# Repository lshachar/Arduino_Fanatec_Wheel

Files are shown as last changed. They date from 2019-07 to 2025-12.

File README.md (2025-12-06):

# Arduino_Fanatec_Wheel
A do-it-yourself steering wheel to Fanatec's wheel base.<br/><br/>
**28.04.2020 Coronavirus update:** Version 1 is out!<br/>
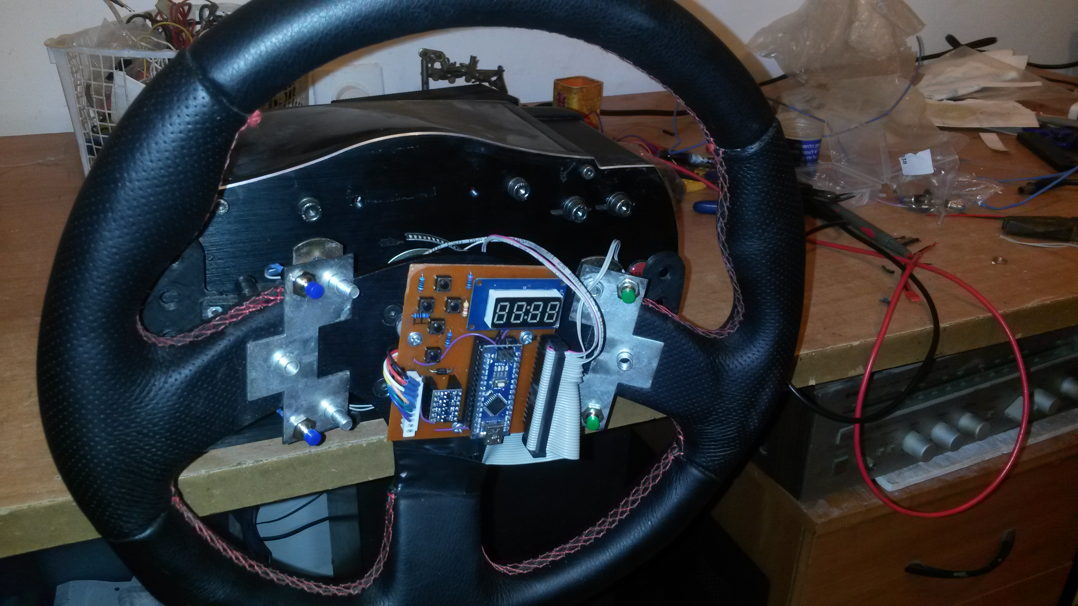
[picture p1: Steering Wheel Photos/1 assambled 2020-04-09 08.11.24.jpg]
Steering wheel assembled

[check out more photos here](https://github.com/lshachar/Arduino_Fanatec_Wheel/tree/master/Steering%20Wheel%20Photos)

*The buttons delay bug is fixed, buttons code is working great!<br/>
*I fixed several large bugs with the SPI communication, which now works flawlessly.<br/>
*Updated schematics - Added a 5 buttons Analog input that feeds into a single analog input on the arduino. You can calibrate your wheel center by using the D-pad and alphanumeric display, without plugging the Arduino to your PC!<br/>
*Added Diode, and connected D2 and D10 together, both changes are necessary! please revise your board to include these changes if you've built one already!<br/>
*Updated board layout - it's possible to either manufacture a single layer board, and solder a few jumper wires for the top layer, or manufacture the complete two-layers board. (I used a CNC machine and milled a single layer board)
________________

**This project is donationware, if my work helped you out** [**maybe get me a beer! :)**](https://paypal.me/lshachar)<br/><br/>
  
Fanatec's wheelbases won't enable any force feedback, unless you have a Fanatec steering wheel attached to it.
With this project, you can use an arduino to communicate with the wheelbase over SPI, which will get the wheelbase working.
You can attach buttons, a D-Pad and an alphanumeric display, for the complete package!

This simplified (schematics) version is enough to let you enable force feedback on your wheelbase,
[use this easy to understand 'breadboard view' simplified schematics](https://github.com/lshachar/Arduino_Fanatec_Wheel/blob/master/schamtics%20arduino%20nano-level%20shifter-fanatec%20round%20plug.png), or [This simplified schematic](https://github.com/lshachar/Arduino_Fanatec_Wheel/blob/master/schamtics%20arduino%20nano-level%20shifter-Simlified.png).

The full PCB supports alphanumeric display, D-pad, and lots of external buttons
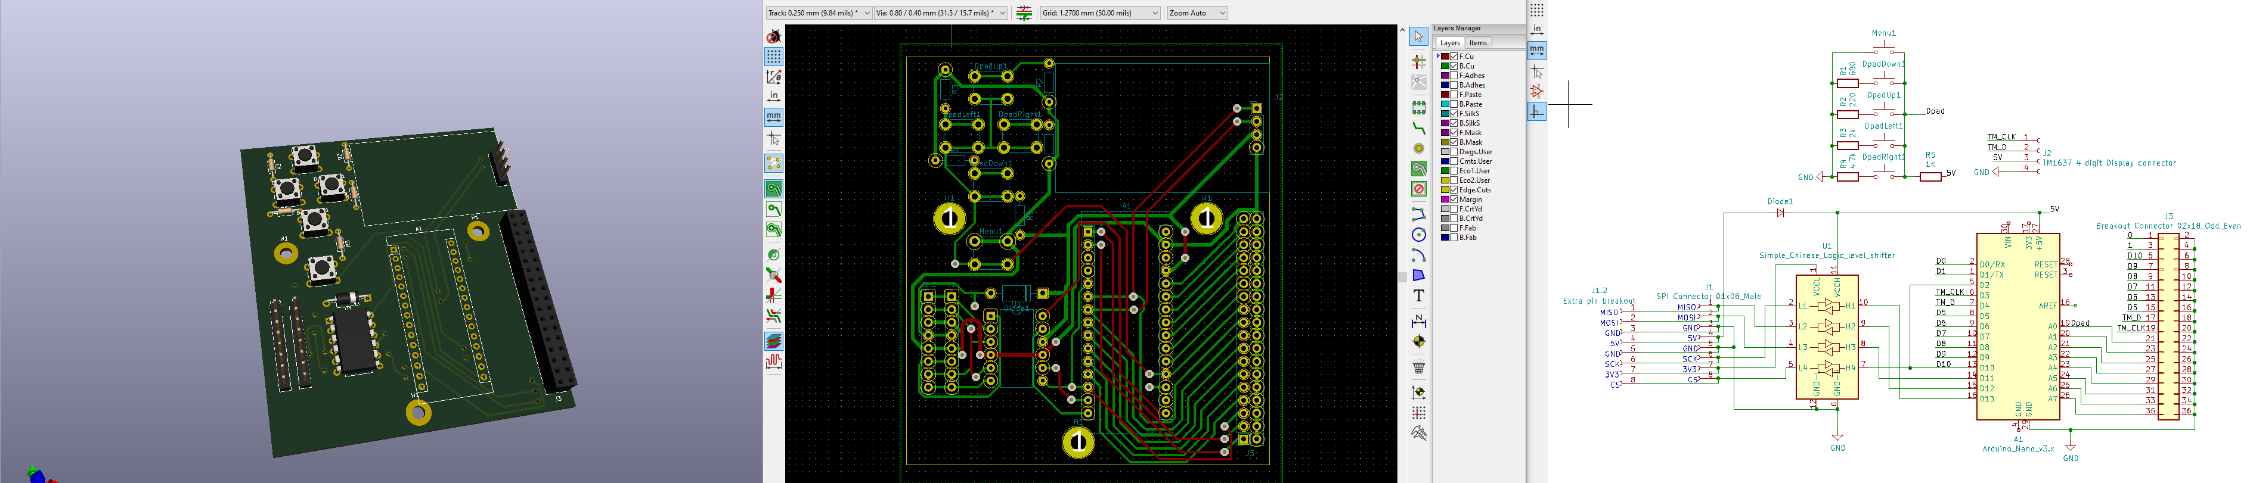
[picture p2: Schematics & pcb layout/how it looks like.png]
full PCB
 (I currently use 6: 2 paddle shifters and 4 buttons on the rim).

Here's a [how to make a male Fanatec SPI connector](Steering%20wheel%20connector%20-%20howto/Readme.md) (what the steering wheel has)<br/>
Also, [Alevale found where to buy the connector](https://github.com/darknao/btClubSportWheel/issues/14#issuecomment-604973137)<br/><br/>
[use this](3d%20Models/fanatec%20adapter%20v1.STL) If you need a simple 3d adapter to attach your physical steering wheel to the wheelbase<br/><br/>

### Several options:
- Use a 5V arduino with a logic level shifter. (recommended, this is what I use. [(here are The schematics)](https://github.com/lshachar/Arduino_Fanatec_Wheel/blob/master/schamtics%20arduino%20nano-level%20shifter-fanatec%20round%20plug.png)
- Use a 5V arduino **without** a logic shifter (can be risky to your precious wheelbase)
- Use a 3.3V arduino (I haven't tried it. They run on 8 MHZ instead of 16 MHZ for the 5V arduinos, but I'm pretty sure 8MHZ should be fast enough.)

Code was tested on arduino Uno and Nano, and works fine. However, they both output 5V and the SPI communication on the wheelbase
is using 3.3V.
It's best to use a level shifter between the two, so there are no chances of damaging the wheelbase (by connecting the 5V arduino 
output to a 3.3V wheelbase input)
However, since the wheelbase is the master and the steering wheel is the slave - MISO is the only *input* channel on the wheelbase,
and it is safe to simply use a voltage divider on the MISO line - to go from 5V level to 3.3V. (The arduino should recognize the 3.3V input signals coming from the wheelbase as high, so there's nothing we have to do there). <br/>
- **Note:** If you do end up going this route, make sure you wire everything up properly, and that you never set SPI as master on the arduino, or you will subject the wheelbase SPI to 5V. (I did subject the wheelbase SPI to 5V by mistake - and nothing got damaged.)<br/><br/>

I recommend using an arduino nano **and** a logic shifter, as seen in the schematics.
- **Note:** The diode is crucial to keep the 5V coming from the wheelbase, and the 5V coming from the computer USB, seperate. the diode will drop the 5V voltage from the wheelbase to ~4.3V, which is fine for the arduino to run on. When you plug the USB cable, the arduino will run on the 5V coming from the computer, and current cannot flow to the wheelbase because of the diode.<br/>
fyi I have connected both power supplies together, and did not have anything go up in smoke. (but this is before I thought about using a diode. DO NOT ATTEMPT THIS YOURSELF.<br/>

[There's a lot of (old) info here](https://github.com/darknao/btClubSportWheel/issues/12)

# What to do if you gotta calibrate your wheelbase center?
On some wheelbases, you can do that directly from the [Fanatec wheel properties page](https://github.com/lshachar/Arduino_Fanatec_Wheel/issues/7). unfortunately it doesn't work on my CSW V2.5.<br/>
You can use the current code to calibrate the wheelbase's center point. (This is needed after a firmware upgrade for the wheelbase) the arduino will translate the alphanumeric display to letters and send them out to the Serial monitor(!). you will need to type in some commands on the Serial monitor, which will look pretty cypheric to you.
Type these characters on the serial monitor, press [return] after each line: <br/><br/>
C		(to change bits on the 3rd byte that affects buttons. C=3rd)
6		(to change (raise) the sixth bit on the 3rd byte, which is the menu button. this will cause the alphanumeric display to turn on and the message '5_1' (equivilent to 'S_1' i.e. 'setting 1') will be printed on the serial monitor.)  
6		(to release the menu button (lower the 6th bit) )  
23		(2 will raise the D-pad button bit, 3 will raise the joystick button bit.)  
23		(to release both buttons, drop both bits)
6		(press the menu button again to exit the menu)  
6		(release the menu button)  
[Watch this If you don't know what I'm talking about](https://www.youtube.com/watch?v=yvhAKxjit8o)  
(Hey - it's not an easy procedure, but it works!)
if you made a PCB with a Dpad and alphanumeric display - you can calibrate the center point without connecting to the computer!
Using the Dpad:
Enter the menu by pressing both up+down bubttons on the Dpad,
S_1 will appear on the serial monitor and on the alphanumeric display,
Press both left+right buttons on the Dpad to calibrate wheel center,
Press both up+down on the Dpad to exit menu. Done!

This project would never have been possible without the work of Darknao on his [BtClubSportWheel - converting any Fanatec CSW steering wheel to a standalone USB version](https://github.com/darknao/btClubSportWheel) project.

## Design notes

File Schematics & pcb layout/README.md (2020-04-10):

I'm keeping the legacy PCB layouts here, as someone may want to use the version 'without display or Dpad' for simplicity.<br/>
please look inside KiCad for the most recent version.<br/>
check out Steering Wheel Photos folder, for photos describing how I have everything connected.<br/><br/>

I did not manufacture this PCB properly in a factory, but rather I milled it on a CNC machine. I used a single layer PCB (for the buttom layer in green), and the top side (red)
was meant to be connected with some jumper wires.<br/>
So, I was using vias on the design as plated through-holes, as means to attach wires to. (AFAIK there will not be holes if you sent the gerber files to a factory. The PCB layout file must be edited to create a hole first!)<br/>
note that I didn't even bother placing some of the lines (appear as white lines in the layout file) since jumper wires can easily cross over each other. with a bit of editing, all these things can be fixed so that you could get a good working PCB right from the factory.<br/>
I see that not all TM1637 display boards have the same connector, you might need to switch the order of some of the pins, or move them from the top right corner of the PCB, towards the D pad buttons, on the top left of the PCB.<br/>
The diode solves the issue I had with connectiong the wheelbase's 5V supply with the USB 5v supply coming from the computer, so it's really important.<br/>
you can use almost all the pins on the large breakout connector (J3) for buttons, except the last two - D0 and D1 on arduino are also the serial communication pins. so they are there just for debugging.<br/>
It would be useful to add another row of 8 pins to the left of J1, in order to have breakout pins for the SPI communications with the wheelbase. <br/>
AREF - there is a via, but it's not used. (it was connected to the + side of the diode, (there is a via there as well)) but it's not used. In fact, using it would create problems with the dpad buttons that are on the layout.<br/><br/>

Good luck!

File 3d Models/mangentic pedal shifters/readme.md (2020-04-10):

Non Commercial -  NOT FOR RESALE - Personal use only. 

Copyright AMSTUDIO 2018 All Rights Reserved

AMSTUDIO
https://www.youtube.com/channel/UCQS1ZB3BVSrBo3tCs7PyfxQ

Magnetic shifters video:
https://www.youtube.com/watch?v=hbHkliQDCx0

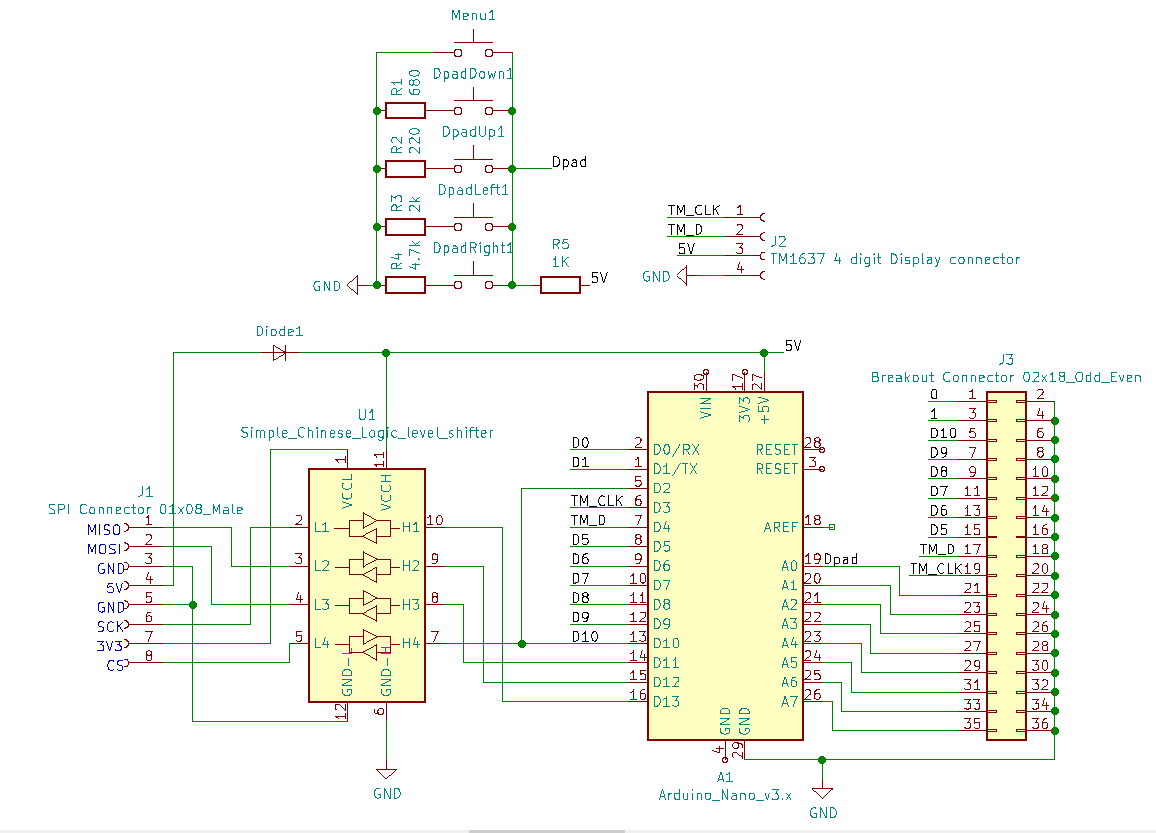
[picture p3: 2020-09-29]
schamtics arduino nano-level shifter-Full.png

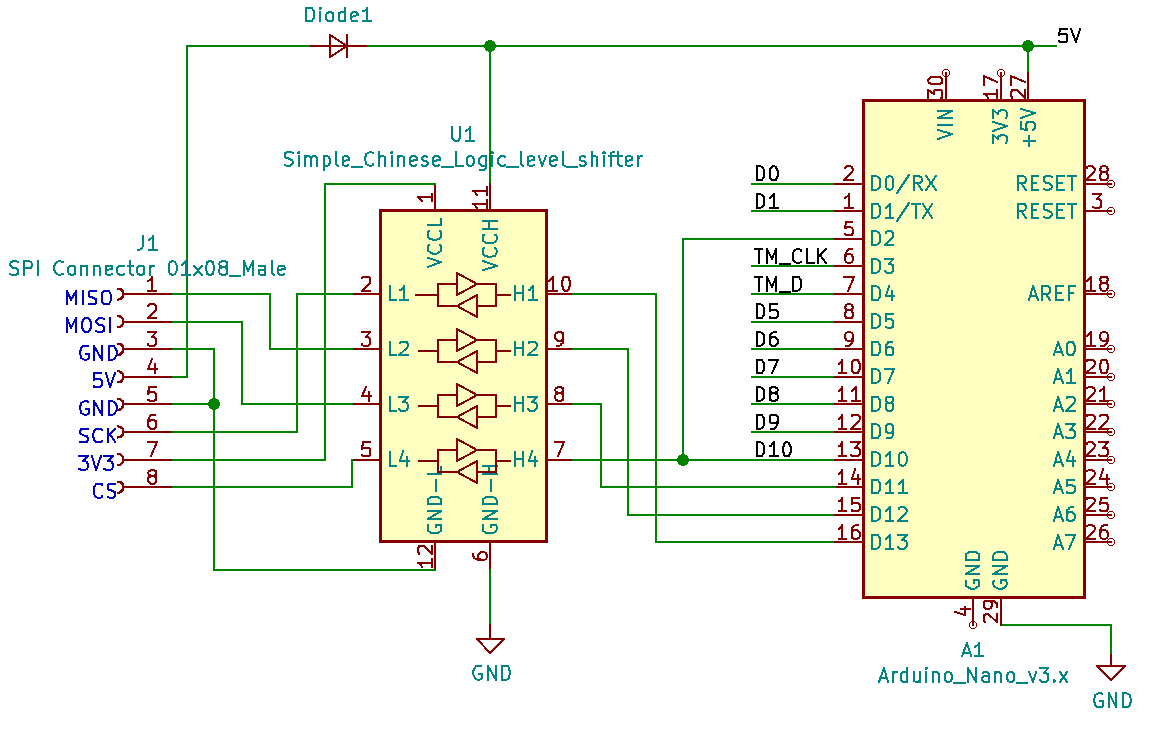
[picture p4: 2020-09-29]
schamtics arduino nano-level shifter-Simlified.png

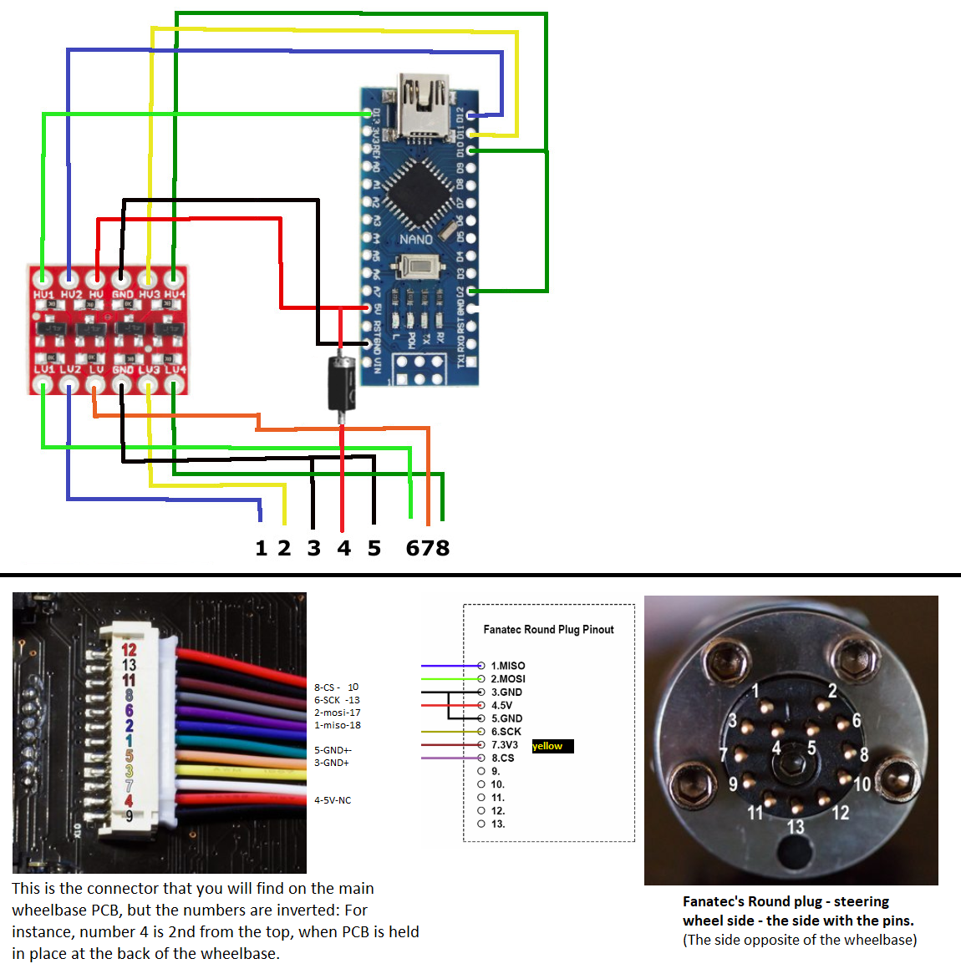
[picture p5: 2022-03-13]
schamtics arduino nano-level shifter-fanatec round plug.png

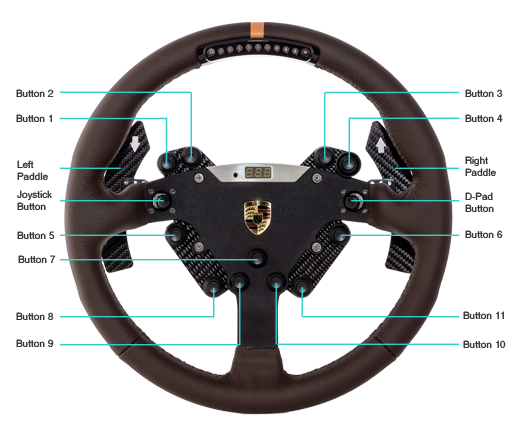
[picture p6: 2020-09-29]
clubsport Porsche 911 buttons.png

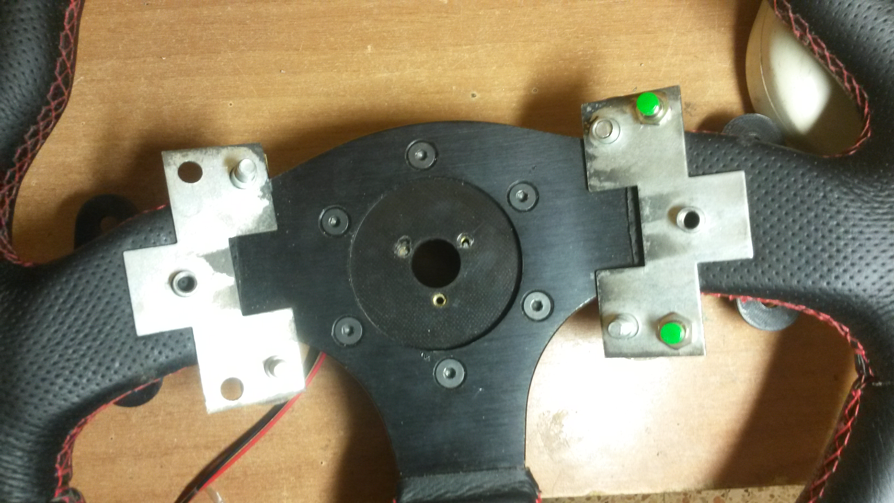
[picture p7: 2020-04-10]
Steering Wheel Photos/2020-03-29 04.42.22.jpg

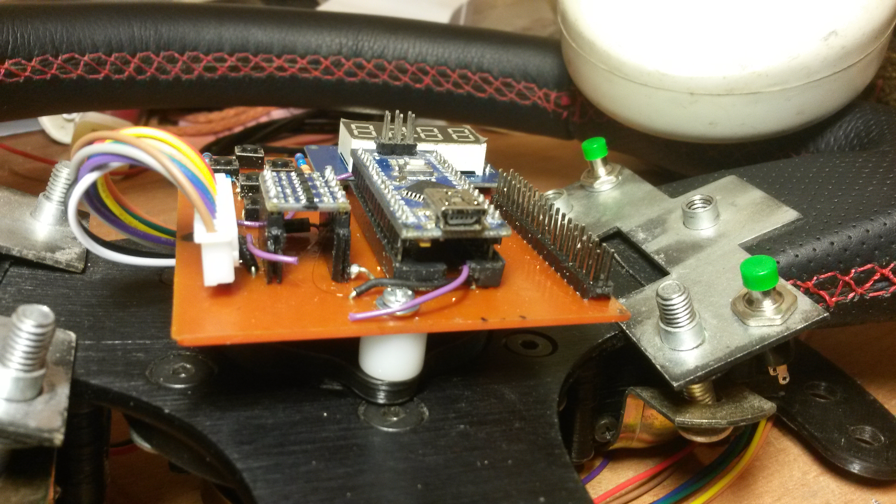
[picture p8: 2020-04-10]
Steering Wheel Photos/2020-03-29 04.53.28.jpg

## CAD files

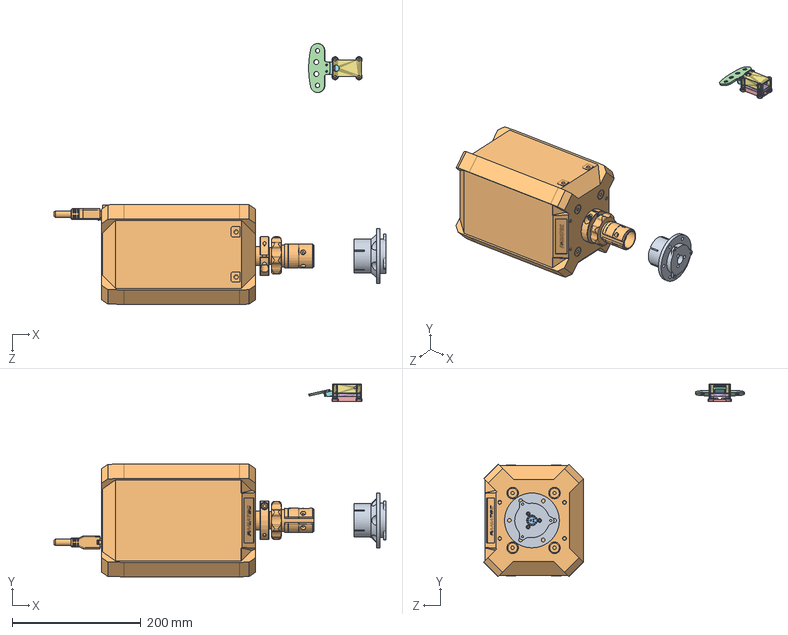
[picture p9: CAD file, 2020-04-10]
3d Models/fanatec adapter & pcb fixtures/arduino fanatec wheel.SLDASM
515.1 x 298.9 x 404.6 mm
fanatec adapter
Fanatec_PodiumWB-DD1-DD2
fanatec SPI connector
f1_paddle
shifter_unit_btm
shifter_unit_switch_stop_plate
shifter_unit_top
paddle_hinge_v2

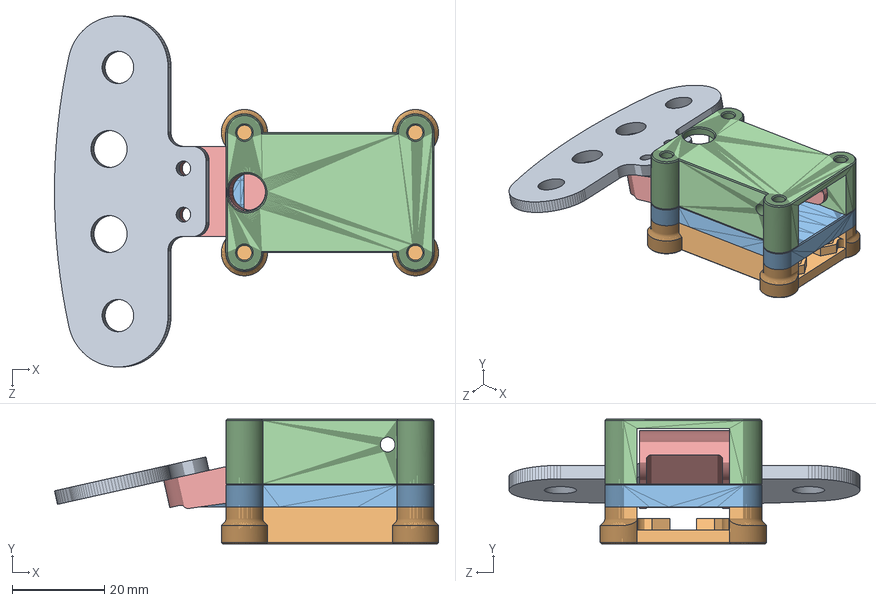
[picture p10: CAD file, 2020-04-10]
3d Models/mangentic pedal shifters/Imported to Solidworks/mangentic pedal shifters assy.SLDASM
83.1 x 27.0 x 75.9 mm
f1_paddle
shifter_unit_btm
shifter_unit_switch_stop_plate
shifter_unit_top
paddle_hinge_v2

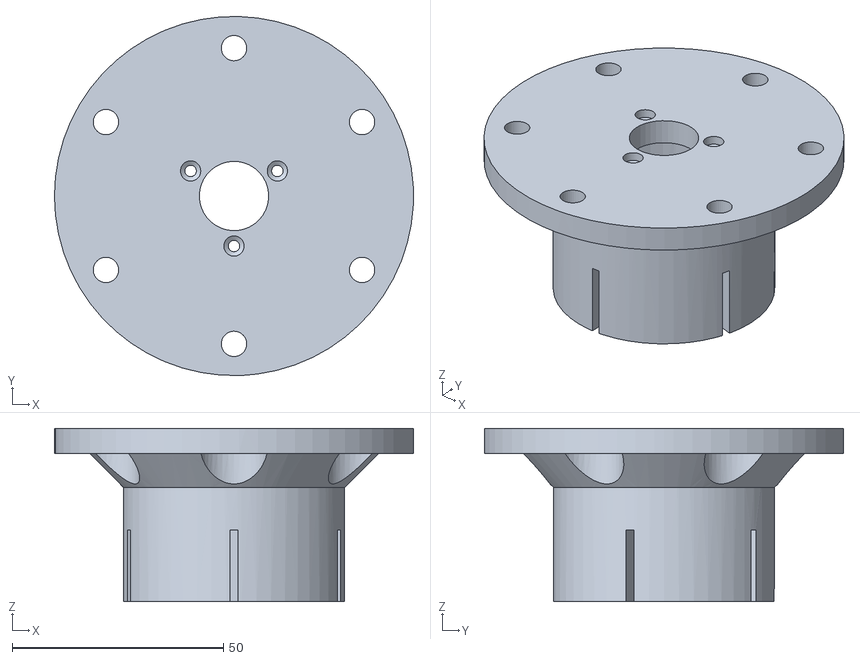
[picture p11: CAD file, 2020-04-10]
3d Models/fanatec adapter & pcb fixtures/fanatec adapter & pcb fixtures exported files/fanatec adapter V2.STL
85.0 x 85.0 x 41.0

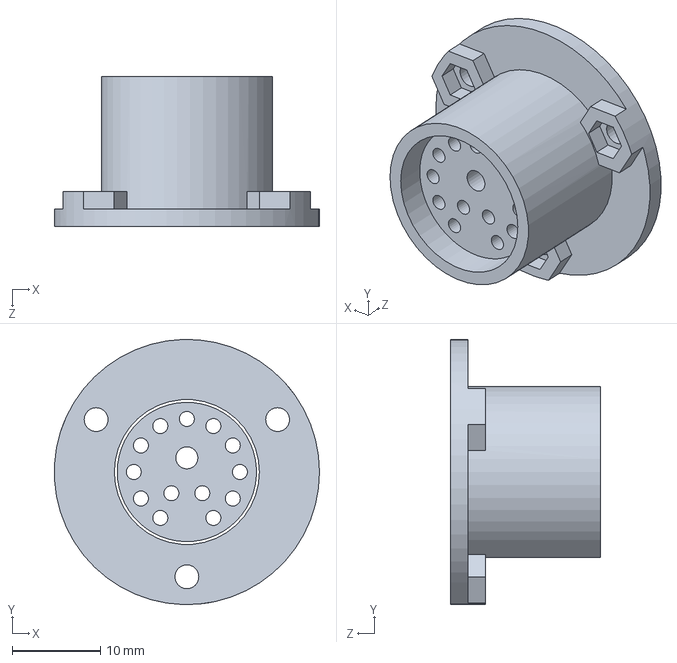
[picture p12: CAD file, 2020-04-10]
3d Models/Fanatec SPI connector/fanatec SPI connector.SLDPRT
30.0 x 30.0 x 17.0 mm

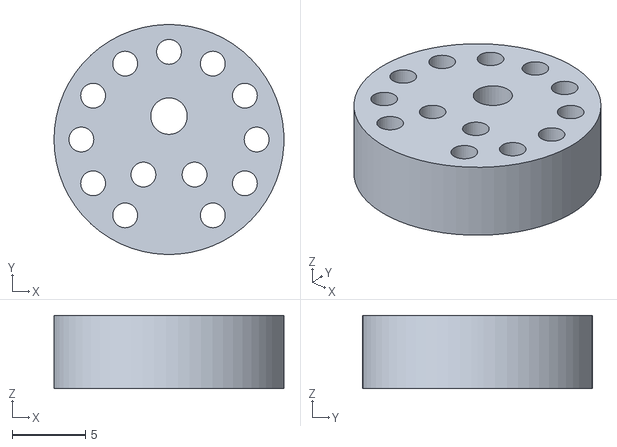
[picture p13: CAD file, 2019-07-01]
3d Models/Fanatec SPI connector/SPI connector exported files/fanatec SPI connector.STL
15.8 x 15.7 x 5.00

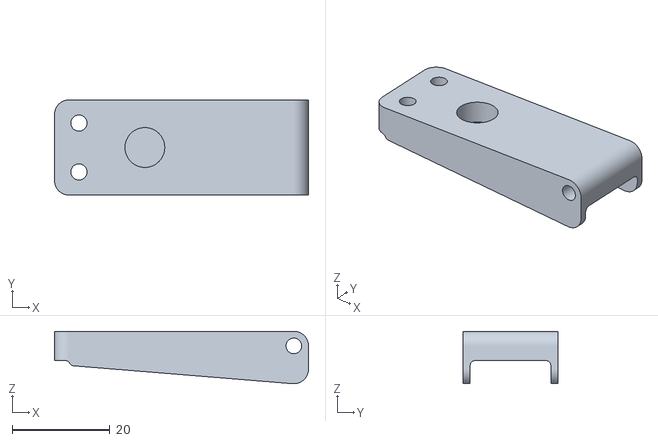
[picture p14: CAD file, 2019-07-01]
3d Models/mangentic pedal shifters/Imported to Solidworks/10mm round magnet (instead of 8) exported files/paddle_hinge_v2.STL
52.0 x 19.5 x 10.7

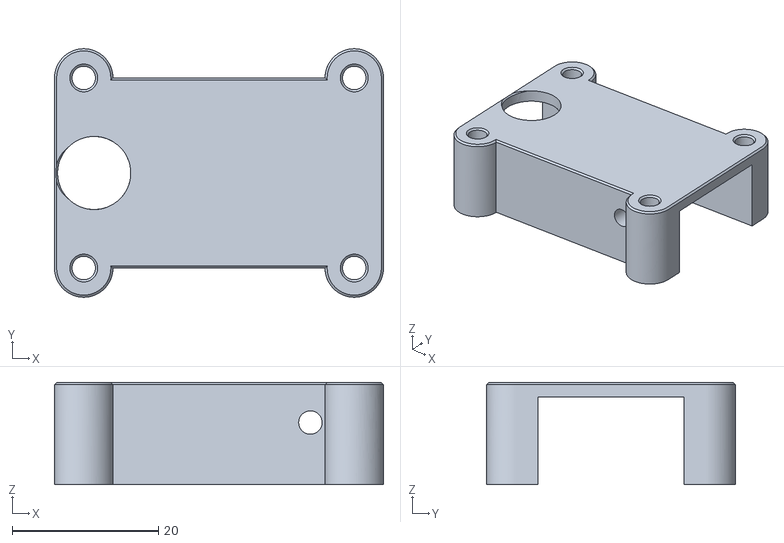
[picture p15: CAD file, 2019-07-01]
3d Models/mangentic pedal shifters/shifter_unit_top-10mm x 5mm magnet (Shachar).STL
45.0 x 34.0 x 14.0

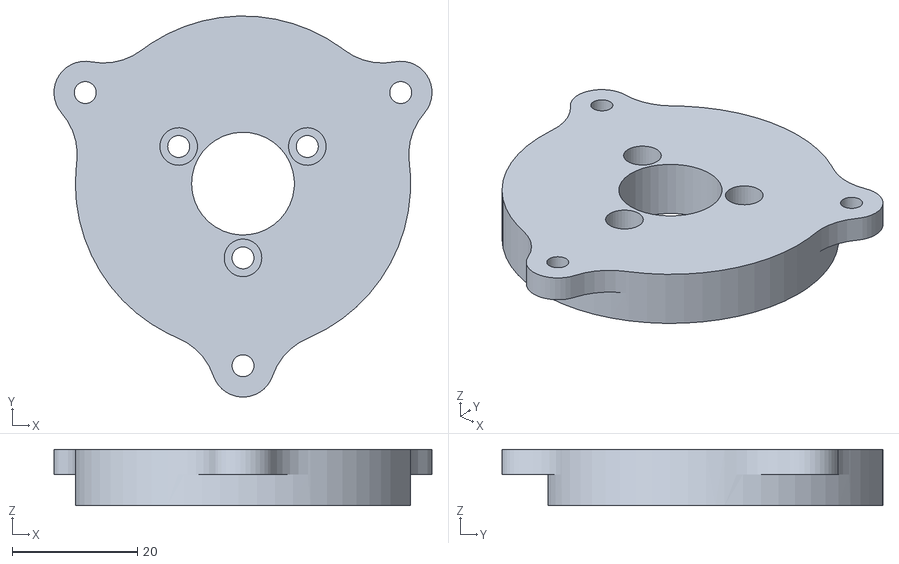
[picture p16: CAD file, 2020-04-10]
3d Models/fanatec adapter & pcb fixtures/fanatec adapter & pcb fixtures exported files/pcb fixture.STL
60.3 x 60.8 x 9.00

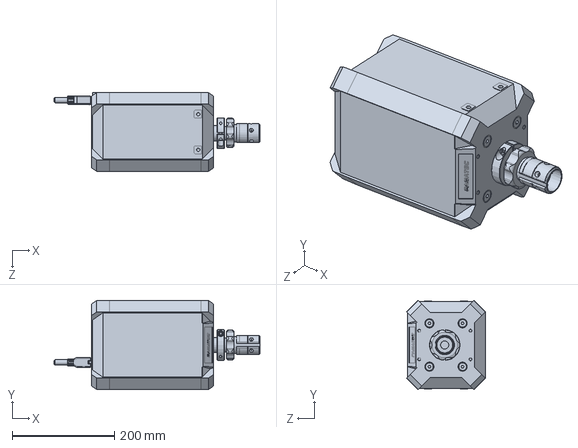
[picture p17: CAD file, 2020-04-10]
3d Models/fanatec adapter & pcb fixtures/Fanatec_PodiumWB-DD1-DD2.SLDPRT
403.6 x 175.0 x 155.0 mm

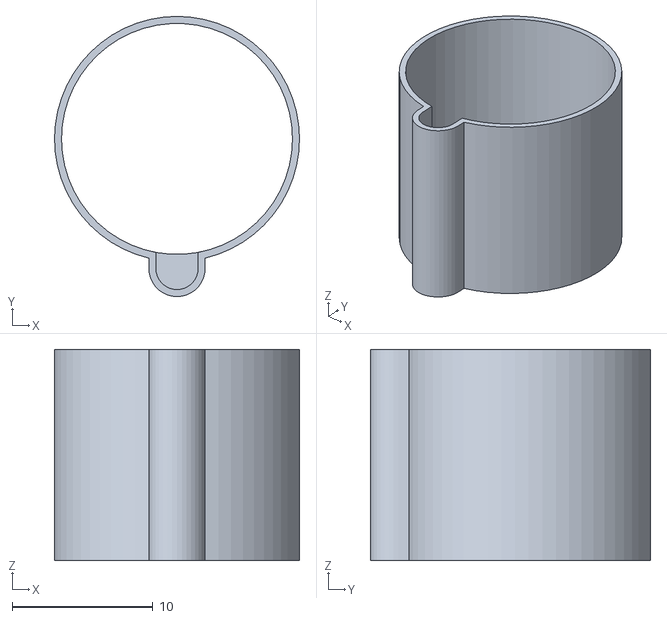
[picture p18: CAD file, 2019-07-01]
3d Models/Fanatec SPI connector/SPI connector exported files/fanatec SPI connector-housing.STL
17.4 x 19.9 x 15.0

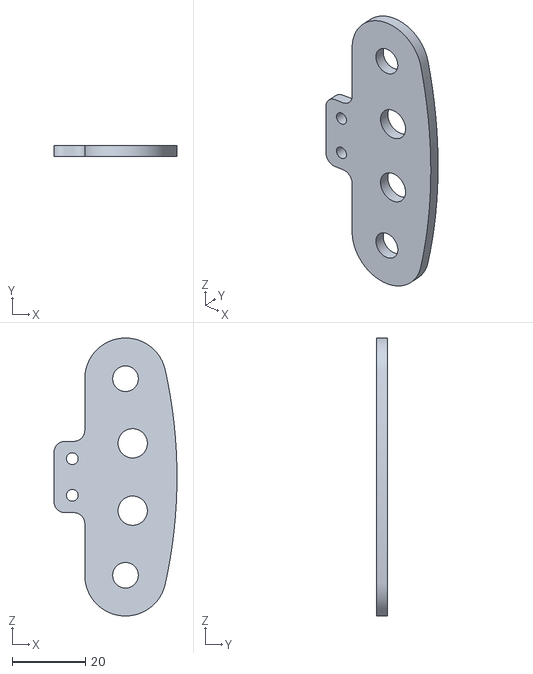
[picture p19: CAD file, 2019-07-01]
3d Models/mangentic pedal shifters/Imported to Solidworks/10mm round magnet (instead of 8) exported files/f1_paddle.STL
33.6 x 3.00 x 75.9

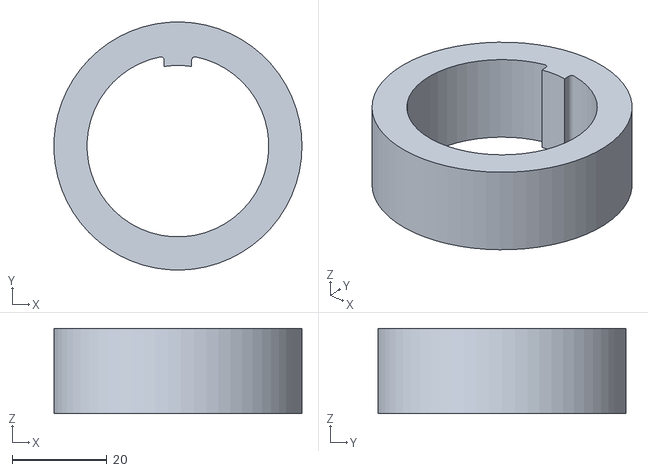
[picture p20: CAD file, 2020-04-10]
3d Models/fanatec adapter & pcb fixtures/fanatec adapter & pcb fixtures exported files/fanatec adapter V2 - a test part to calibrate print on base.STL
52.3 x 52.3 x 18.0

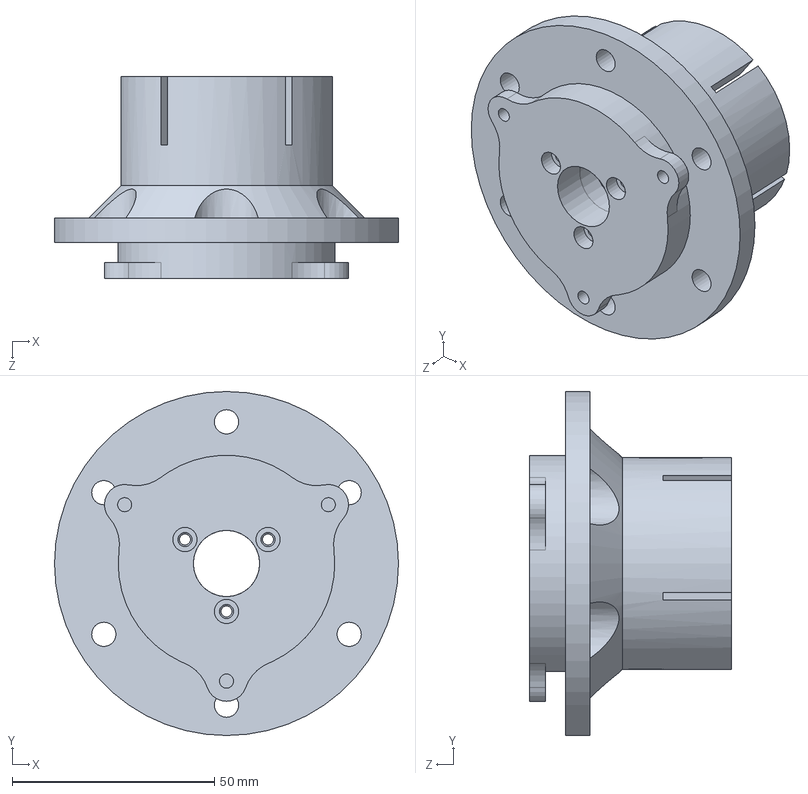
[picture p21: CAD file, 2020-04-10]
3d Models/fanatec adapter & pcb fixtures/fanatec adapter.SLDPRT
85.0 x 85.0 x 50.0 mm

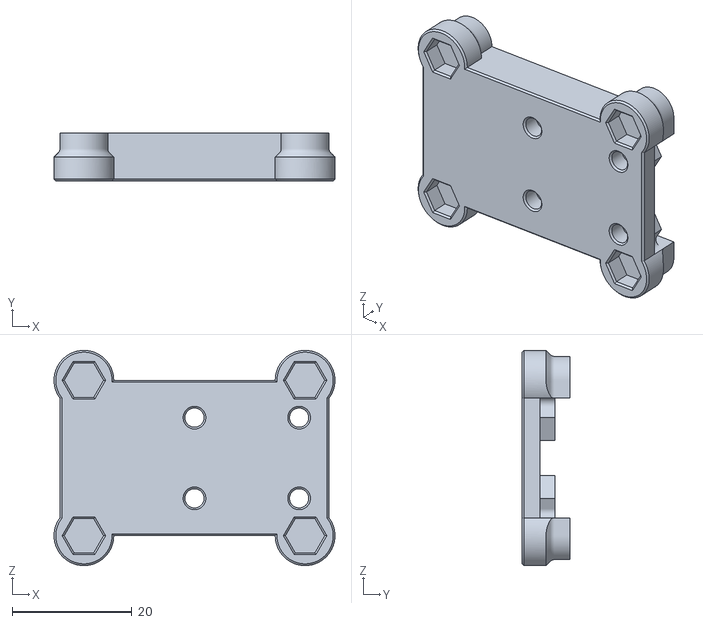
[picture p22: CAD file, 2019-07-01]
3d Models/mangentic pedal shifters/Imported to Solidworks/10mm round magnet (instead of 8) exported files/shifter_unit_btm.STL
47.0 x 8.00 x 36.0

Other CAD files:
3d Models/mangentic pedal shifters/Imported to Solidworks/paddle_hinge_v2.SLDPRT
3d Models/mangentic pedal shifters/paddle_hinge_v2-10mm x 5mm magnet (Shachar).STL
3d Models/mangentic pedal shifters/Imported to Solidworks/10mm round magnet (instead of 8) exported files/shifter_unit_top.STL
3d Models/mangentic pedal shifters/Imported to Solidworks/f1_paddle.SLDPRT
3d Models/fanatec adapter & pcb fixtures/fanatec adapter & pcb fixtures exported files/fanatec adapter V2.x_t
3d Models/fanatec adapter & pcb fixtures/fanatec adapter & pcb fixtures exported files/fanatec adapter v1.STL
3d Models/fanatec adapter & pcb fixtures/fanatec adapter & pcb fixtures exported files/pcb fixture.x_t
3d Models/mangentic pedal shifters/Imported to Solidworks/10mm round magnet (instead of 8) exported files/shifter_unit_switch_stop_plate.STL
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

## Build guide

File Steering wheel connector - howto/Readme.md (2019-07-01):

Extract the female plastic SPI connector from your wheelbase
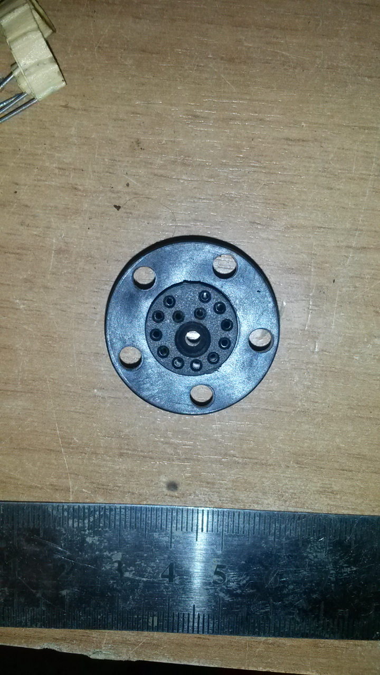
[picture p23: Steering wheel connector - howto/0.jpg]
Fanatec female SPI connector


And the wired connector that connects to the wheelbase PCB
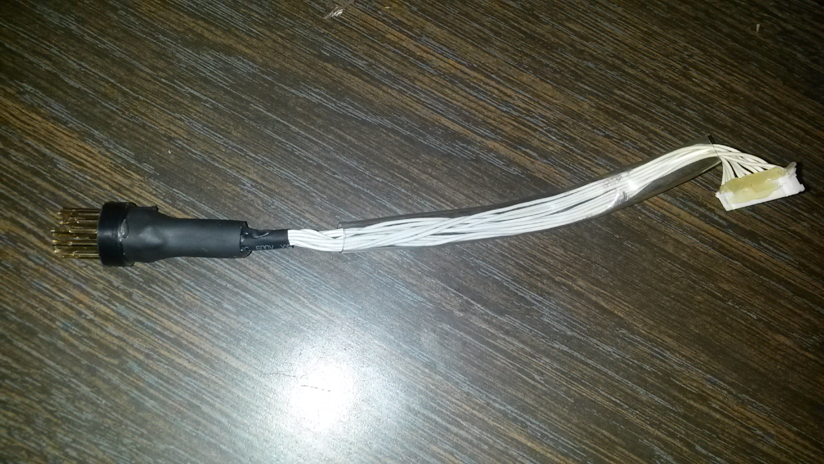
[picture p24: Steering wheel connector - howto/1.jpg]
wired connector

Use the small ellen screw (that you had to remove) to assemble the two pieces back together.

solder some pins on pieces of wires (I recommend you to get something golden. I was lazy! It might rust out eventually!)
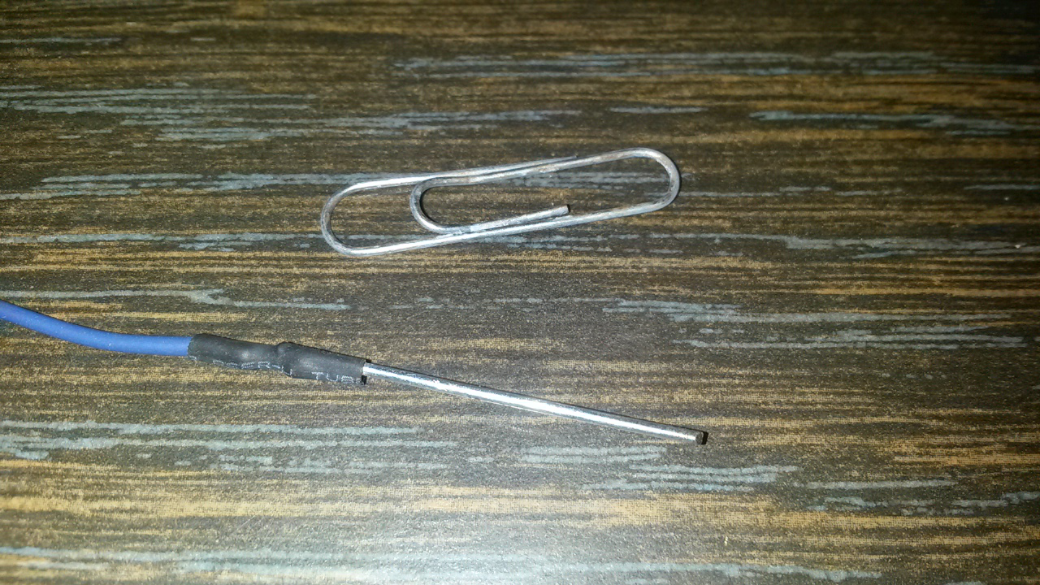
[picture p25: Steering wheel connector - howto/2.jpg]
wire with pin

The connector has 13 connections, but you probably won't need all of them. However adding more will be impossible later. So I just did all of them.

[3d print this part](3d%20Models/Fanatec%20SPI%20connector/fanatec%20SPI%20connector-housing.STL)

put a small piece of adhesive tape to cover all the holes of the female plastic part. (don't use anything fancy, if it's really sticky mess it up a ittle bit with some finger oil - touch the sticky side.)
The 3d printed part should fit with the aligning indentation mark as shown in the photo. (indentation pointing down, Allen screw is at the top) See that it fits, and take it off.
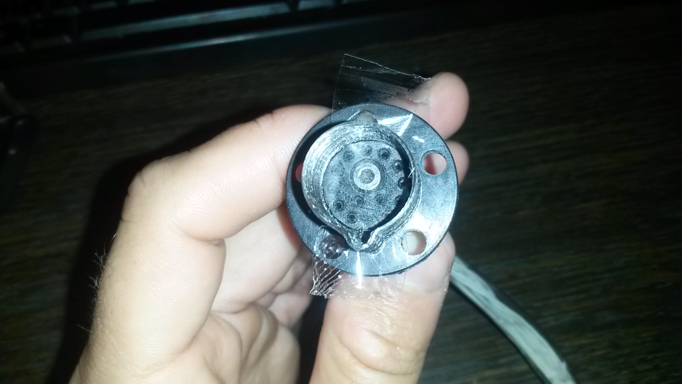
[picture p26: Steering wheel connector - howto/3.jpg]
adhesive tape and 3dprint


force all the pins through the adhesive tape.
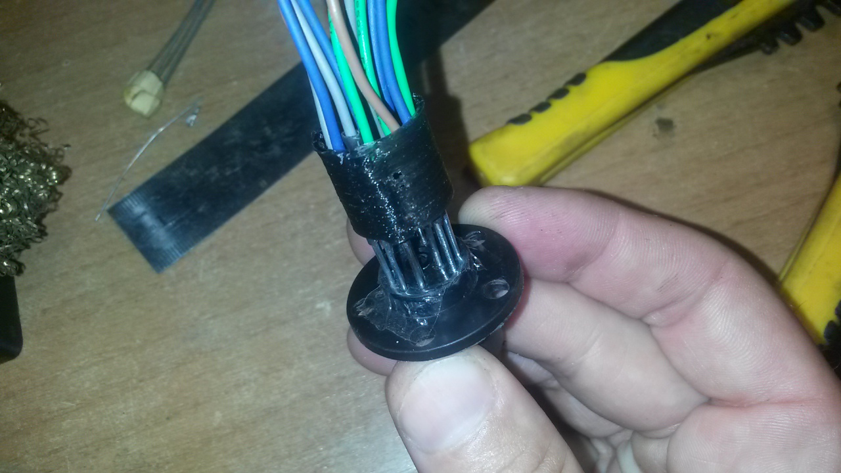
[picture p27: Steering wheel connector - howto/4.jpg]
with wires


put the 3d plastic part back to its place
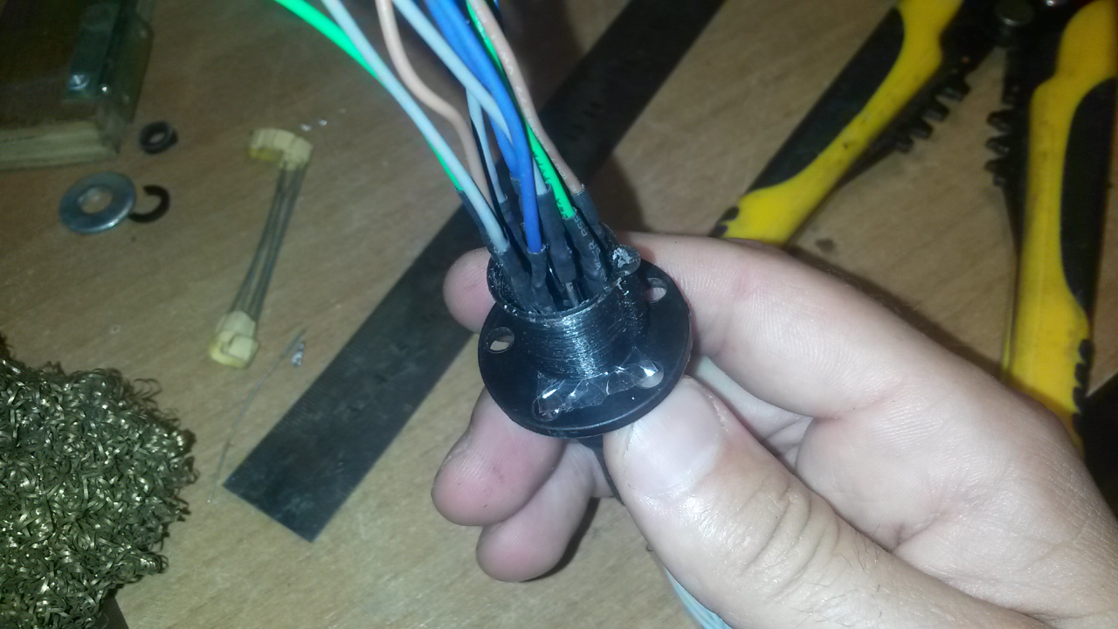
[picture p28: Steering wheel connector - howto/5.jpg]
ready to cast


you are now ready to cast your connector in Epoxy resin.
Use 2 hours cure time epoxy, or you are not likely to fill in all the air gaps by the time the epoxy sets.
I only had 5 minutes epoxy lying around, so I have to do it in another time... to be continued.
(after the epoxy sets, release your new connector, and probably break the 3d printed part where it overlapped with the connector.)

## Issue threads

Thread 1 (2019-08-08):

Buttons

devActive527, 2019-08-08:
Well done. I didn't do the tests, but I see you implemented the buttons. Are they working properly? What do you think there is a chance using arduino uno to additionally handle several buttons and e.g. display data on hd44780 or some other display?

Closed 2019-08-10.

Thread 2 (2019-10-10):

Made the connector with an Nano, Level Shifter, the schematic and code, but no good

Jonbakhol, 2019-10-10:
@lshachar

Hi Ishachar, I used the connection schema (the good one, not mine)
I soldered all wires correctly to the Level Shifter and to the pins. I uploaded the sketch arduino_fanatec_wheel.ino provided on https://github.com/lshachar/Arduino_Fanatec_Wheel/blob/master/arduino_fanatec_wheel.ino

And plugged it in the wheelbase. But no ClubSport Porshe 918 RSR is shown.

Is there something else I have to do? Press the reset button on the Nano or something else?

I also have an Teensy 3.2 with the Teensy code, and that one is working perfectly.

Any help would be appreciated.

Thanks
JonBakhol

lshachar, 2019-10-10:
Hi! no reset is needed. Do you have both pins 3 & 5 connected to ground?
If you have a logic analizer, or a scope see if you get clock signal on fanatec's pin 8. (or simply attach an LED and a resistor to HV4 on the level shifter)

Jonbakhol, 2019-10-10:
Thanks for coming back so quick.

Yes I connected them both to ground. Measured with an ohm meter all pins to be sure no short-circuits are there (accept pin 3 & 5).
Scopes etc I  don't have. I do have some LED's and resistors. Between which point do I need to check it? HV4 and ?

Few more (maybe stupid) questions:
Do I need to connect the modified USB cable to it? (without the 5V cable)
Could it be the cheap Chinese Nano?
Do I need to put in the missing pins 9 till 13 (even there is no connection between the Nano and the pins)

Thanks for now

lshachar, 2019-10-10:
(Alright this got messy because I didn't finish my initial reply but pressed comment by mistake.)

Hi! no reset is needed. Do you have both pins 3 & 5 connected to ground?
try plugging your arduino to the PC by usb. It might get the thing to recognize if your grounds / +5v lines aren't connected well.
If you have a logic analizer, or a scope, test your logic shifter. you are suppose to get information coming in from the base on CS, MOSI, CLK lines. the arduino should send out data on MISO line.

Last thing... could be interference... Darknao said he had issues with interference so I had a ground wire twisted around each data line. I don't think it's likely to solve your problem and I hardly think it was necessary to twist some ground lines.

_____________________
answering your 2nd comment
> Do I need to connect the modified USB cable to it? (without the 5V cable)

well, The simple answer is - preferrably yes.
or at least, disconnect fanatec's pin #4  (5v supply) from the arduino, before you connect the arduino to the PC by USB.
This way, you're making sure that the arduino gets voltage from the computer and you don't connect the two power supplies to each other.
However, I definitely forgot to do that myself several times and nothing went up in smoke.
In any case you really want to get the arduino connected to the PC because you need to open the serial monitor on the PC and tell me what you see there!

> Could it be the cheap Chinese Nano?

Yes, that's what I use.

> Do I need to put in the missing pins 9 till 13 (even there is no connection between the Nano and the pins)

nope. you don't need to do anything with them.

> Thanks for coming back so quick.

lucky you.. I was on the computer :)

> Scopes etc I don't have. I do have some LED's and resistors. Between which point do I need to check it? HV4 and ?

... and ground. This is kind of long to explain, I basically offered you to check that the logic shifter was working properly, with a single LED, which isn't the best test. so I take it back, it will be difficult for you to understand if there is data transmission on the line with a single LED. instead you can test that the logic shifter is working properly. By raising one side of the logic shifter (LV# or HV#) to high - the other side should also go high. but each side will only output the voltage that it gets on its power supply pin (marked by LV or HV on the schematics, next to the GND pin)
so, if you give +5v and ground to the HV side, and you give +3v and ground to the LV side, and then you give, for instance, +3v to LV1, then HV1 should go up to +5v. you can test it with a multimeter. if you have the project right now on a breadboard, this should be a really simple test to do..
So, you are trying to debug electronically. but try the serial monitor first.

Jonbakhol, 2019-10-11:
Goodmorning @lshachar ,

I connected the Arduino to the PC with an intact USB cable (so no 5V cable cut) and checked with the multimeter the currents on the Level Shifter, on LV side and on HV side.
These are the values:

              LV side                                                                                HV side

GND + LV1 (pin 6) = 2,28 V                                                     GND + HV1 = 2,11 V
GND = LV2 (pin 1) = 3,26 V                                                     GND = HV2 = 4,66 V
GND = LV   (pin 7) = 3,26 V                                                     GND = HV   = 4,66 V
GND = LV3 (pin 2) = 3,26 V                                                     GND = HV3 = 4,66 V
GND = LV4 (pin 8) = 3,26 V                                                     GND = HV4 = 4,66 V

Except pin 6 (LV1 and HV1) all seems fine, or isn't it?
What could be the problem that pin 6 (LV1 and HV1) is that low?

Can I try to change pin6 (which is connected to D13) to e.q. D10 and update the sketch?

Many thanks again.

Jonbakhol

devActive527, 2019-10-24:
@lshachar ,

Hi. I don't know if it will help in some way, but I noticed that when I connect the 5v power supply to the arduino shortly after turning on the base there are no crc errors, while when I do it too early or too late there are errors. I discovered this while reading the com port from arduino. Maybe this is the reason for the buttons not working? Simply 5v power supply to the steering wheel should appear with some delay, and in our connection is given immediately after switching on. I do not know how it relates to the communication between the base and the steering wheel is just my theory. Can you verify it somehow?

lshachar, 2019-11-16:
CRC errors means you have bad wiring / bad ground / noise issue. Since the button delay problem happens even when there are no CRC errors - the two aren't related.

lshachar, 2020-04-28:
[The new diagram](https://github.com/lshachar/Arduino_Fanatec_Wheel/blob/master/schamtics%20arduino%20nano-level%20shifter-fanatec%20round%20plug.png) and fixes I made to the SPI communication, means everything works much better now.

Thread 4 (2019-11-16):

DIY arduino steering wheel to fanatec csl elite wheelbase

Pistolidas, 2019-11-16:
Hello All,

Has enyone been able to get either the Teensy 3.2 or the Arduino Nano working on a Fanatec CLS Elite V1?
I tried both, but no succes. :(

Regards,

Pistolidas

MagnusThome, 2019-12-16:
I have it working on a CSL Elite+ base

https://rejsa.nu/forum/viewtopic.php?p=1588680#1588680

Pistolidas, 2019-12-16:
Hello Magnus,

Thnaks for your message. Would you be willing to share your connections and arduino sketch?
Are you using a teensy 3.2?

Looking forward to your reply.

Regards,

Pistolidas

MagnusThome, 2019-12-17:
Hi!

I use an Arduino Nano with his code just as is with no changes:

https://github.com/lshachar/Arduino_Fanatec_Wheel/blob/master/arduino_fanatec_wheel.ino

I also connected everything 100% according to his diagram:

https://github.com/lshachar/Arduino_Fanatec_Wheel/blob/master/schamtics%20arduino%20nano-level%20shifter-fanatec%20round%20plug.png

It works right away. I did almost make a mistake though connecting the wires to the home made connector going into the base unit’s axle connector. I misread the connection diagram mirrored, to be viewed as you solder the pins towards the base unit, but it’s viewed in the picture from the base outwards. Just double, triple, quadruple check all the wiring is my tip.

Email me again if you have any more questions!

/Magnus

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

Pistolidas, 2019-12-18:
Hello Magnus,

Thanks for very much for your reply.
I also made this unit and it works on a Clusport V1 wheelbase but not on my Elite V1 wheelbase. Would you know which firmware version and which driver version you have installed for your CSL Elite wheel base.

Kind regards,

Pistolidas

MagnusThome, 2019-12-18:
The Fanatec propertiy page in Windows says:

PC driver: 328
WB FW: 630

But I've found a problem, depending on what Aduino board I use it works or not.

With the working board:
- When I plug it in to the base the base unit's red power led fades down and up once and then the Clubsport wheel shows up on the windows property page
- All four data pins have signals, measured with a scope

The not working board:
- When I plug it in to the base the base unit's red power led fades down and up coninously. The Clubsport wheel never shows up on the windows property page
- Three data pins have signals, measured with a scope. They look like on the working board but they are there for a second, gone for second, there for a second, and so on.
- D12 is low all the time. No signal visible at all like on the working board. Tried a 4K7 pull up resistor to 3V3 but no change.

lshachar, 2019-12-26:
> I also made this unit and it works on a Clusport V1 wheelbase but not on my Elite V1 wheelbase.
> Pistolidas

Does your Elite V1 Wheelbase works with a different wheel?
In case you haven't tried - I suppose that the wheelbase is at fault
If you have tried and it works - I'm really surprised! Follow MagnusThome's advice: 'Just double, triple, quadruple check all the wiring is my tip'

MagnusThome, 2019-12-26:
Pistolidas, did you connect the two ground pins to each other? Its a long shot but might affect the function a bit differently on different base version, who knows...

lshachar, 2019-12-27:
> Pistolidas, did you connect the two ground pins to each other? Its a long shot but might affect the function a bit differently on different base version, who knows...
It actually isn't a long shot, without the two grounds connected, my CSW V2.5 will not recognize anything. it must be connected in order to work.

Pistolidas, 2019-12-27:
Hello Magnus and Ishachar, thanks for your help. I ordered a new Arduino Nano and I'll give this a try this weekend.
With the "old" Nano I have connected the GND to both pins 3 and 5 of the round connector to the wheel base, as described here:

https://github.com/lshachar/Arduino_Fanatec_Wheel/blob/master/schamtics%20arduino%20nano-level%20shifter-fanatec%20round%20plug.png

I double checked the connections ones more and all seems to be okay.

I have two wheels for my Elite wheel base the Fanatec XBOX P1 and the Fanatec McLaren GT3 both work properly.

I have also tried the Teensy 3.2 setup as described here: https://github.com/darknao/btClubSportWheel/issues/12

This also only worked on a Clubsport V1 and not on my Elite V1.

I hope the new Nano will work but I have my doubts, to be continued.......

Pistolidas, 2019-12-29:
It worked, I replaced the Aruino Nano and it recognized it as the Clubsport Porsche 918 RSR wheel, Force Feedback works.
Thanks for your help!!

DavDaddy, 2020-12-13:
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

Not to hijack this thread but does anyone have any idea if this will work with the ClubSport v1 wheelbase?

I know the Porsche 918 wheel is compatible so I figure it should but I wanted to double check before I rip my DIY HOTAS apart?

Thanks.

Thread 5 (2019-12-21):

Adapting to Clubsport V2.5

matt0hait, 2019-12-21:
I'm working on adapting this to my Clubsport V2.5 using an ESP32. I'm a little stumped on the pinout. It seems different from the one provided in the repository. I thought that the Fanatec rims were compatible between the bases. I'm limited in my options since I don't have a Fanatec rim yet. This is what I found so far by probing the base's PCB:

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

Anyone else take a crack at this yet?

MagnusThome, 2019-12-22:
I'm a bit confused with your pinout numbering. This is the original connector numbering?

The four uncommented pins are 5V, GND, +D, -D

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

MagnusThome, 2019-12-22:
This pinout works on a CSL Elite + I have here and it defintely works with the same steering wheels as with your Clubsport V2.5

matt0hait, 2019-12-22:
Just re-probed with my oscilloscope, (using the pin map you provided) I have 5V on pin 11 &13. Pin 4 definitely connects to ground for me. I was able to continuity check it to a Vss pin. Is it possible that the rims provide 5V to the base through pin 4?

I'll have some level converters later this week. Saw some diagnostic pins on the inside of the base. Gonna see if they can spill the beans.

matt0hait, 2019-12-26:
(Using your pin map again) Pin 3 does output 3.3V, but once it is pulled to ground the signals become alive. I'm still not receiving any signals on MISO or MOSI. Using the serial interface on the arduino doesn't create any signals either. Think I'm going to need to try another arduino.
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

lshachar, 2019-12-26:
When I initially tried to implement this I wanted to go the ESP32 route, but as far as I can remember - nobody was able to put it in ISP Slave mode. Even though some documentations were referring that.
I advise you to try getting your ESP to receive data as an ISP slave, before attempting to use the code.
(Actually, I would advise you to get it working on an arduino first... would probably make your life much easier)

danieleibarra, 2019-12-28:
Has anyone already found the solution to go on a v2.5 engine?

lshachar, 2019-12-28:
> Has anyone already found the solution to go on a v2.5 engine?
I just changed the title, to explain the the OP is trying to adapt to an ESP32 from an Arduino;
My project is based on an arduino and a CSW V2.5. So to answer your question - yes, there is a solution for a V2.5...

lshachar, 2019-12-28:
>Pin 4 definitely connects to ground for me. I was able to continuity check it to a Vss pin. Is it possible that the rims provide 5V to the base through pin 4?
>Pin 3 does output 3.3V, but once it is pulled to ground the signals become alive.

I'm pretty sure you're reading the connector mirrored. the picture I gave is the side *on the rim*, wheres the side you're probing is the connector side *in the wheelbase*.

> Is it possible that the rims provide 5V to the base through pin 4?

The rim gets 5V from the wheelbase, not the other way around.

danieleibarra, 2019-12-28:
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

Ah that's fine, so how would the montage be? because I would like to have it

matt0hait, 2019-12-28:
That picture of the oscilloscope is with an Arduino Leonardo.Still no dice. Going to pick up another Arduino soon and see if that fixes the issue.

danieleibarra, 2019-12-29:
> That picture of the oscilloscope is with an Arduino Leonardo.Still no dice. Going to pick up another Arduino soon and see if that fixes the issue.

Is the assembly but not yet confirmed to work?

lshachar, 2019-12-30:
@danieleibarra , I can't understand your English.

danieleibarra, 2019-12-30:
> @danieleibarra , I can't understand your English.

I mean if there is already something that works 100%

lshachar, 2019-12-30:
I keep telling you **YES**. the project is fully working with an arduino and many fanatec wheelbases. including CSW V2.5.

danieleibarra, 2020-01-06:
Ok I have the sketch for adolescence 3.2 I just don't know where they would go, help me

lshachar, 2020-01-08:
not befoe you could explain in English what your issue is.

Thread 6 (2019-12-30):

New pcb, what is the big gpio connector intended for?

MagnusThome, 2019-12-30:
Just curious if you have any specific plans using the large gpio connector that you've added to the pcb?

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

Why I'm wondering is that the delay on using the shifter buttons currently neccesitates a separate solution for the shifter buttons.

lshachar, 2020-02-10:
Hi Magnus!
I wanted to have a breakout board for all the gpio pins on the board... they should eventually get used for buttons, once we squash that delay bug ;)

Just like you, I'm currently using a separate solution for the shifter buttons.

Closed 2020-04-28.

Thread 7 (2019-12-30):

Wheel center calibration now available in the Windows property pages

MagnusThome, 2019-12-30:
This button does the same as the instruction on the first github page?

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

lshachar, 2020-02-10:
that's great news! I'll try it out next time I'm on my sim :)
Thanks a lot!

MagnusThome, 2020-02-10:
Version numbers in upper right corner:

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

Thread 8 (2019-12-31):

Startup delay

MagnusThome, 2019-12-31:
When I turn on my CSL Elite + base unit most of the time the Arduino/wheel isn't detected and I have to restart the Arduino with it's reset button after some seconds after turning everything on, then all is well.

I guess it's because the Arduino is booting to fast compared to the wheel base? So I added a one second delay right at the beginning of setup() and now the Arduino/Wheel is detected properly _every_ time I turn on the base unit.

lshachar, 2020-02-10:
That's weird, I'm guessing it's an issue with the SPI interface, as the arduino is always looking for the start of a sequence sent by the wheelbase, and then it just sends off the same message out. I'm going to blindly add your delay suggestion to setup() (because on my csw this was never an issue)
Thanks!

sabifa, 2020-02-14:
Hey! I know this issue is closed already but today I received my quick release and built the circuit on a breadboard to find out that its not working.
I had to press the reset button on my nano a couple of times and it only worked like 3 / 10 times.

After some digging in the code I thought that I should try to remove the delay which was added a couple of days ago. After I removed it, it worked 100% of the times I've tried! (5/5)

It would be nice if someone else could also try this out so we can be sure if its needed or not.

My specs:
CSL Elite + Wheelbase
Wheelbase Firmware 662
PC Driver 346

MagnusThome, 2020-02-14:
Interesting! With my nano board it's exactly the opposite. I think it's all
down to the general problems to get a stable communication even though all
my wires are only 2-3 cm long. Very odd.

Den fre 14 feb. 2020 18:59Fabian Klöckner <notifications@github.com> skrev:

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

lshachar, 2020-02-14:
Hmm.. thank you @sabifa!

lshachar, 2020-04-28:
Those issues were likely because of bugs that I recently fixed in the spi communication...

Closed 2020-02-10.

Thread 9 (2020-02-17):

Adapting to Arduino Pro Micro 3.3V 8 Mhz

sabifa, 2020-02-17:
Hey!

I've tested this code using an Arduino Nano + Level Shifter and it worked like a charm! As I want to design the smallest possible PCB so that it fits into my Fanatec QR Adapter (52mm to 70mm) I want to use a 3.3V powered Arduino so I don't have to use a level shifter which is quite big.

@lshachar stated that he didn't try a 3.3V Arduino yet, because he thinks that it will be a problem later on if we want to use the buttons. As the button functionality isn't yet fully implemented and I'm planning to use something else this won't bother me. I just need the base to think that a Fanatec rim is attached to it! 😅

I only found a few 3.3V powered Arduino's and made my choice for the Pro Micro.

I have changed the ``CS_ISR`` pin to 3, as pin 3 maps to interrup 0 (INT0) on the board. More info about the board can be obtained [here](https://learn.sparkfun.com/tutorials/pro-micro--fio-v3-hookup-guide/all#hardware-overview-pro-micro).

I've wired everything up and connected it to my base, but it instantly disconnects from my pc and reboots (the rev lights light up and it spins to center itself). So there is definitely something not working as it should.

The strange thing is, if I disconnect pin 4 from the Fanatec QR (5V) and connect the pro micro to my pc via usb to have a look at the serialport, my base **does not reconnect** if I connect the arduino to it 🤔
The serialport only says that "incoming data crc8 mismatch!" is wrong. I printed the MISO and MOSI buffers and they are:
```
MOSI:0x00 0x00 0x00 0x00 0x00 0x00 0x00 0x00 0x00 0x00 0x00 0x00 0x00 0x00 0x00 0x00 0x00 0x00 0x00 0x00 0x00 0x00 0x00 0x00 0x00 0x00 0x00 0x00 0x00 0x00 0x00 0x00 0x00
MISO:0xA5 0x03 0x00 0x00 0x00 0x00 0x00 0x00 0x00 0x00 0x00 0x00 0x00 0x00 0x00 0x00 0x00 0x00 0x00 0x00 0x00 0x00 0x00 0x00 0x00 0x00 0x00 0x00 0x00 0x00 0x00 0x13 0x25
```

Just in case, here is my wiring:
4 - RAW
7 - VCC
3 - GND
5 - GND
1 - 14
2 - 16
6 - 15
8 - 3

Here is the pinout of the Pro Micro as found on the Sparkfun Site:
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

Please let me know if I can do something else to provide more information that could help to solve the issue. Did maybe one of you already try another 3.3V Arduino, if so did it work for you? I'm not fixed with the pro micro!

Thanks!

MagnusThome, 2020-02-17:
Can the 32u4 act as SPI slave like the 328p? Curious to what choices we have to chose as controller chip.

MagnusThome, 2020-02-17:
I think the Pro Mini is 328P 3.3V and it's very small.

sabifa, 2020-02-17:
Reading [that thread](https://forum.arduino.cc/index.php?topic=255594.0) it seems like that it can not be used as a spi slave out of the box..
They wrote that they somehow grounded pin 17 (rx led) and it worked. I'm not exactly sure how to do that though. Desolder the led and just connect the ground pad to the other one?

sabifa, 2020-02-17:
> I think the Pro Mini is 328P 3.3V and it's very small.

Yes I saw the Pro Mini as well but as it doesn't have a USB port I thought it would be better to use a different chip, just to keep things as simple as possible.

sabifa, 2020-02-17:
Okay I just ordered a Pro Mini 3.3V and will report back in a couple of days when it arrives. I think the Pro Mini will be better compared to the Pro Micro as it uses the same 328 as the nano (as you already said) :sweat_smile:

lshachar, 2020-02-18:
> Okay I just ordered a Pro Mini 3.3V and will report back in a couple of days when it arrives.

I think it should work out just fine for you. :)

sabifa, 2020-02-19:
Just received the pro mini and uploaded the sketch. Unfortunately the same happens, I connect it to my base and it instantly disconnects and restarts.
I guess we should close this issue here and start a new one for the pro mini. I will do some more testing to see if I find something whats causing the issue. Does someone else have a pro mini 3.3v as well and could try it please?

sabifa, 2020-02-22:
Did some more testing and couldn't make it work 😞
What are your thoughts on this? Maybe it's the 8 MHz which stop it from working.

smollda, 2020-02-28:
I found this :
"Atmega328P Datasheet 19.5.2,
19.5.2 SPSR - SPI Status Register
Bit 0 - SPI2X: Double SPI Speed Bit
When this bit is written logic one the SPI speed (SCK Frequency) will be doubled when the SPI is in Master
mode (see Table 19-5). This means that the minimum SCK period will be two CPU clock periods.
When the SPI is configured as Slave, the SPI is only guaranteed to work at fosc/4 or lower.

Thus, 8 MHz transfers should not be counted on to work in Slave mode, only in Master mode."

posted on arduino forum here https://forum.arduino.cc/index.php?topic=424260.0 (post #3]

I was also looking into using a 3,3v arduino for more simple solution, but it seems it won't work.

sabifa, 2020-02-28:
Good catch! So 8 MHz is just not enough.

After some more digging about running Arduinos at 3v3 and 16 Mhz+ I found the [Adafruit Trinket M0](https://www.adafruit.com/product/3500). Judging from the specs it doesn't look too bad! 3.3V @48Mhz. (thats 3x the speed of the 328p, is there something like too fast?)

About using it as a spi slave I've found [this thread](https://forums.adafruit.com/viewtopic.php?f=25&t=94366) which doesn't contain much information unfortunately.

smollda, 2020-03-02:
I've also found this https://flytron.com/multicopter-parts/116-3v-16mhz-pro-mini-with-100-arduino-compatibility-.html , but it's a bit too expensive (for what it is). I've had arduino nano, level shifter and PCB prototype board lying around, so I'll just use that. It's not going to be pretty though ...

lshachar, 2020-04-28:
You might want to give the 3.3V arduino another go. I debugged a few things on the SPI communication, it's a lot more reliable now. [notice the changes in the diagram](https://github.com/lshachar/Arduino_Fanatec_Wheel/blob/master/schamtics%20arduino%20nano-level%20shifter-fanatec%20round%20plug.png) (Added Diode, and D2 is connected to D10). the latter is really important for proper SPI communication and may fix the issue that you've had before.

sabifa, 2020-04-28:
I will! Thank's for your effort in this project 🚀

Could you tell us a bit more why it's necessary to connect D2 and D10? Is it because of the Slave Select?
Sorry if I missed it but what kind of Diode do I exactly need?

lshachar, 2020-04-28:
:)
I'm using an interrupt routine on D2: Every time that the cable select pin is pulled high by the wheelbase (right after a transaction ends) the arduino gets ready for a new data transaction.

but I still had a problem where the incoming SPI data was pushed a couple of bits out of alignment. That problem would come and go. So for example the 1st bit of the 1st byte sent by the wheelbase, would sometimes register as the 2nd or 3rd bit of the 1st byte in the arduino, etc. And once that happens - all the packet is corrupted and you have nothing but CRC8 errors.
I found out that for the serial parallel interface to work correctly, even in slave mode, it also expects the CS line to drop in the beginning of a transaction. Which also resets the single-byte SPI index, So that the next incoming bit will be registered correctly as the first bit in the buffer.

The diode is needed to separate the wheelbase 5V power supply from the computer USB 5V power supply.
I'm not sure what schematic are you using for 3.3V arduino, but I can assume that when you plug the arduino to a computer via usb, the arduino gets 3.3V from both the wheelbase and its internal 5V to 3.3V voltage regulator. If that is indeed the case, Then yes, you should add the diode.

Any old 0.5A diode should be enough. I believe the one I used is about 3A.

sabifa, 2020-04-28:
Thank you very much for that detailed explanation, it's very interesting! I also saw that the button inputs are now working correctly without the delay, that's super handy to build a custom wheel.

I will try the 3.3V arduino again and will report back :)

sabifa, 2020-07-29:
Sorry for the long delay!
Today I tested the new code with a regular 3.3V Pro Mini which unfortunately did not fix my problems. The same happened as before (rebase restarts, power led slowly fades from on to off).

I also purchased an [Arduino V2 Pro Mini](https://www.tinyosshop.com/index.php?route=product/product&product_id=275) which offers the possibility to run 16 MHz on 3.3V. With that it works in about 3 / 10 cases, which is not that good - but hey at least it works, kind of 😅
In the fail cases my wheelbase restarts as with the regular 3.3V Pro Mini.

I also noticed that the wheelbase thinks the D-Pad button is held down the whole time, did anyone of you experience that as well?

I'm not to sure what causes the issues, maybe it's the 16 MHz which aren't officially supported when running 3.3V or it's the long jumper cables connecting the Pro Mini to the Fanatec QR pins.

If I find the time I will create a small pcb to make sure the jumper cables are not a problem here and report back!

Hilpas, 2020-12-15:
Has somebody  tried it again?, I'm currently trying to get it running on my pro Micro but i got similar MISO/MOSI results as you got initially. My wheelbase isnt restarting or anything like this tough. My Wiring is the same apart from 3.3v not being connected. Unfortunately no wheel is recognised by the wheelbase.

Is it set that the Processor frequency is not enough or is it just a Atmega328P at 3.3v thing? Has anybody got it working by now?

sabifa, 2020-12-15:
I suspect that 8 MHz is not fast enough as I couldn't make it work with a pro micro either.

Try to buy a Pro Mini V2 which is able to run 16 MHz at 3.3V and you should be good.
You can find more Infos here #13

Hilpas, 2020-12-16:
Oh havent seen that conversation. Will give the Pro Mini V2 a shot and see if that works out for me. Thank you for your investigations!

Hilpas, 2023-06-04:
I am still using it in this configuration Pro Mini V2 16Mhz 3.3V. Its working flawlessly for me and its the only wheel i use.
I made my own Quickrelease Adapter that replicates the original Fanatec Connector.
https://www.thingiverse.com/thing:5168903

Kuillemaul, 2023-10-08:
Where can you buy Pro Mini V2's now?

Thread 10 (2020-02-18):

Issue with turning the wheelbase off?

lshachar, 2020-02-18:
Hi guys,
I have this thing running on a CSW V2.5, and I cannot turn the wheelbase off by holding the red 'start' button. (I'm assuming it's because that the wheelbase is trying to shut the rim off before powering down, but the rim just keep repeating "Hey! I'm a rim!")

I'm wondering if anyone else has the same problem or not? and what wheelbase are you using?
Thank you.

MagnusThome, 2020-02-18:
Do you have the USB connected? It'll drive power back into the wheel.

lshachar, 2020-02-18:
usb disconnected, and I'm pushing it for even longer.
thanks for the feedback Magnus. (csl wheelbase iirc)

sabifa, 2020-02-25:
Just tried it and I am able to power it off just as I'm used to with an original Fanatec rim.
I also have the csl elite + as Magnus.

lshachar, 2020-03-24:
After reflashing the firmware (to the same, latest one) I don't have this issue any more.

Closed 2020-03-24.

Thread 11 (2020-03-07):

incoming data crc8 mismatch

smollda, 2020-03-07:
Hello, I've connected arduino nano with logic level shifter and this is the message I'm getting, when connecting to serial interface of the arduino. The wheel is acting weird, sometimes it would keep restarting itself, sometimes it works. However, driver software shows Elite steering wheel P1 connected, sometimes it's the BMW one, sometimes Porsche (not sure which type). Also it shows that all the buttons are being pressed randomly.
I have double checked the wiring, but I'll do that again.
I have even used it for a while in ACC, I just had to unmap all the fanatec buttons, as I was getting fake inputs.
Any suggestions? Could it be bad wiring issue? Or maybe bad arduino nano clone?

lshachar, 2020-03-08:
...and you're also recieving the 'incoming data crc8 mismatch' message on the serial monitor?
sounds like you have a bad connection / wrong connection / noise problem.
try twisting another wire around each data wire (mosi, miso, clk) and connecting those wires to ground.
if you can get your hands on an osciloscope, you should be able to see if the lines are noisy.
maybe it's a bad level shifter?

smollda, 2020-03-08:
Hi, thanks for the quick response! After some testing today I can say your "noise" theory is probably true. I made second testing circuit with different arduino and different level shifter and after turning on, serial monitor showed about 50% crc8 mismatch messages mixed with what looked like 3 hex numbers (I assume those were correct messages). I was also using laptop running on baterry at that time, which might have helped ... ? No buttons were being pressed randomly. The wheel appeared as a Porsche 918 RSR steering wheel.
Anyway, I'll make a new properly soldered connector and probably even custom PCB to fit arduino and level shifter and try to make some sort of shielding for data wires.
I also have access to an oscilloscope at work, so if the new circuit fails, I'll check what's going on with those data lines.
Good news is, after installing new beta driver and wheel + motor firmware and connecting the new testing circuit, the calibration issue was gone. I just had to calibrate wheel center using the new driver (version 356)

lshachar, 2020-04-28:
there should be a lot less CRC8 errors now that I fixed a few SPI communication bugs

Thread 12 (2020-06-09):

Encoders, Joysticks, and LED support

BlakePries, 2020-06-09:
I am currently working on making a DIY wheel for my Fanatec base. Looking through the current code and documentation, it appears that there is support for mapping all of the existing buttons from the Fanatec wheels. However, I don't see any mention of the encoders, joysticks, or led rev lights. Most Fanatec wheels have a "funkyswitch" which is a 4-directional d-pad/joystick that also has an encoder built in. Is it possible to add support for that input?

Also, I am currently working on 3d modeling a DIY electrical connector that uses inexpensive header pins so there isn't a need to do the molding using an existing connector,

lshachar, 2020-06-11:
Hi there,
You are correct, there's no support for LEDS / encoders / joysticks in the code. however, I feel like all the heavy lifting is already done in the code, so it should be very straightforward to implement these quite easily, if you have Arduino programming experience. good luck!

andrewkerr5, 2020-08-27:
> I am currently working on making a DIY wheel for my Fanatec base. Looking through the current code and documentation, it appears that there is support for mapping all of the existing buttons from the Fanatec wheels. However, I don't see any mention of the encoders, joysticks, or led rev lights. Most Fanatec wheels have a "funkyswitch" which is a 4-directional d-pad/joystick that also has an encoder built in. Is it possible to add support for that input?
>
> Also, I am currently working on 3d modeling a DIY electrical connector that uses inexpensive header pins so there isn't a need to do the molding using an existing connector,

how did you get on with the model of the connector, im thinking of doing something similar, did you find any suitable pins?

EtienneGameSeed, 2020-10-29:
Hi,
If you're interested I'm selling a board based on Teensy LC, with which can deals with buttons, encoder, joystick, RGB leds, 7 segment display and rumble motors. There's an 8 pin jst 2.0 connector so the connection to a Fanatec QR is easy
But it is not based on Ishachar code and not open source :
https://www.electroseed.fr/shop/product_info.php?products_id=351

Fish2, 2020-11-07:
@EtienneGameSeed out of interest do the inputs and outputs go throw the Fanatec wheel base ? so my main question is will I be able to configure the leds in Fanalab ?

lshachar, 2020-11-07:
they do, and you will.

EtienneGameSeed, 2020-11-08:
Yes I confirm, it wheel behave exactly like a Fanatec wheel, and you'll even be able to configure FFB from the wheel as with a Fanatec wheel

Shane87F3Ng, 2022-03-07:
>

Hello Ishachar,

first of all, thx very much for your work, that is just awesome!
I have one question about how to add additional buttons / encoders..
Do i need to change to another wheel than the Porsche RSR? or just modify the button matrix and bytes?

thomaswang04, 2023-12-28:
I know this is an old thread but I did some poking in the code and figured out how the joystick code works for at least the porche 918 rsr in the base code. returnData[5] is for the x axis and returnData[6] is for the Y axis. 0x00 and 0xff are center position. 0x00 to 0x7f is negative x/y where 0x7f is the farthest the joystick goes. Then 0x80 is the opposite side of the x/y axis which goes all the way back to 0xff which returns to center.

I spent like an hour trying manually adjusting values before trying to cycle through each value and discovering how it works.

hopefully this helps @Airnautique if he is still working on this or anyone else who reads this thread.

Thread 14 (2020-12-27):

Proposed additions to the schematics

DavDaddy, 2020-12-27:
Hello I wanted to see if you'd be interested in adding a couple alternate schematic images?  I edited yours to show an Arduino Uno in place of the nano and also both using a single voltage divider on the MISO line in place of the level shifter.

If you could give them a quick look to make sure I didn't get anything wrong?  Then I can issue a pull request if you'd like to add them to the main repository here?

thanks!

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

lshachar, 2021-03-07:
Hi, thank you for your work!
I'm not sure if merely replacing the arduino nano with an uno helps out many users; since it only contributes by showing the physical pins location on the board. As you know, regardless of their pinout location, they are exactly the same pins. That is not surprising since an Arduino uno and a nano have the same exact functionality, allabit in a different form factor.

I'm not completely at ease about publishing exact directions about how to remove the logic level shifter, and using a voltage divider and apparently (as you have found out) stepping up the MOSI from the wheelbase to the 5v arduino input - so, I wouldn't like to add that schematic to the repository. (Since there's a high risk of feeding 5v into your expensive Fanatec wheelbase)
However, you can reattach the schematic that you put up with the voltage regulator (and transistor). If someone digs them up from here and understands the risks - I have no problem with that!

The ATMEGA328 datasheet states: digital inputs transition from Low to High happens at 0.6 * Vcc, or 3V. Now, AFAIR the Fanatec wheelbase MOSI outputs at 3.3V. (You would have to check if I actually remember that correctly!)
This means that you shouldn't have to level shift the MOSI line. Maybe check your connections and voltages? feed your arduino from a potentiometer and check in what voltage does it actually reads High?

If you still want to step up the (3.3V?) MOSI signal to 5V, you will need a non-inverting level shifter. [See the one in the first answer here](https://electronics.stackexchange.com/questions/107382/use-bjt-transistor-as-a-switch-without-inverting-the-signal)

tahir51, 2021-10-02:
Hi Ishachar. Thanks so much for sharing. I am a total noob when it comes to electronics but I will still try it. Could you tell me which diode would be best as I need to order it? I didn't want to open a new thread for this.

cihaneren, 2022-05-03:
Actually as another noob at electronics, I was looking for the correct diode for this project and I saw your question @tahir51 :) @lshachar could you please share the diode name with us ? And a huge thank you for your amazing project ! 👍

lshachar, 2022-05-03:
1N4001.
it really doesn't matter what diode you use, as long as its max current is more than 0.25W.

you're welcome :) ,
This project is donationware, if my work helped you out [maybe get me a beer! :)](https://paypal.me/lshachar?locale.x=en_US)

Alexbox364, 2023-05-20:
Hi everyone, and thank you for the amazing work you shared here.
I’m currently building my own Porsche 911 GT3 R steering wheel based on turn project : https://simracing-pc.de/en/2022/12/14/turn-racing-diy-project-911-gt3-r-2023-diy-steering-wheel/

I managed to establish SPI communication with my DD1 base and run 24 buttons. I’ll investigate using the encoder capability of SPI protocol.

what I did not manage to do is get enough power from the wheel to run the arduino. I have to hook up the arduino’s USB to the computer.

when I try to get power from the base only, it turns on for 2 second and then the base’s screen turns black.

I tried to get power from pin 4 (+5V) And 9 (USB +5V), both have same effect.

did someone manage to get power from wheelbase for the above shown schematics without any issue?

Cheers!

Bob2345de, 2024-03-10:
Re: „ when I try to get power from the base only, it turns on for 2 second and then the base’s screen turns black.“

Many thanks for this comment. Had been trying to get this to work at first without usb connection to the Arduino. Had the same issue. With the Nano connected to usb works perfectly with my DD1. Am surprised that the Arduino’s minimal 5v draw is tripping over current. This could be the same issue causing CSL DDs to turn off when the wheel is plugged in. Will attempt to get the code running on a STM32 bluepill at 3v3.

Huge thanks to the author for his work!

lshachar, 2024-03-11:
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

You could try adding a capacitor on the 5v line to stabilize the initial current draw. But really you'd want a scope to see that initial current draw yourself. If it's big - there might be something wrong with your Arduino/wiring. I would also experiment with finding the tripping point for the 5v supply on your wheelbase.
I suppose you don't have a scope.
The Arduino should not draw more than 200ma I'd think.
5v
v=i*r
r=25ohm
Use a 25ohm resistor for a 200ma current on a 5v line. Make sure it's a 5v line though. If the wheelbase is okay with that, then the problem is probably your Arduino.

Bob2345de, 2024-03-14:
So, I took apart a fanatec wheel today to wire up a logic analyser and see what is actually going on when conecting a wheel to a DD1.

As you can see in the pics below, the spi communication starts within about 200ms of connecting the wheel. Could it be that newer bases are expecting that communication to be establiched earlier that older ones did and, therefore, are shutting down when that doesn't happen in time?

From what I have been able to establish the normal arduino boot process (using the boot loader) takes approx 2000ms, ten times the expected duration. Also, when using USB power, my arduino works without issue, perhaps because it can establish the SPI cinnection quickly because it has already booted prior to attaching the wheel. Did those who have this working on newer bases flash the firmwire via ISP without a bootloader, allowing the arduino to get SPI up in time? Will tty that on the WE.

You'll notice that top 2 traces (3v3 and 5v) go high a bit later than the SPI lines. Those are the shortest pins (marginally) on my wheel, the delay varies directly with the speed I plug in the wheel, therefore, I believe, but am not certain, that's insignificant.

BTW current draw definitly isn't causing the shutdowns, both the Fanatec wheel and my arduino nano pull the same 20-30mA.

Plug in slowly:
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

Plug in quickly:
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

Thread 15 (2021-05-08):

Two cables Connector

karelknight, 2021-05-08:
Thank you for this amazing project.
I am wondering if it'd be possible to use the "2 cables connectors inside the base to simplify and maybe improve the reliability of the fanatec plug.
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
These are classic connectors, is there something i'm missing?

lshachar, 2021-05-08:
Hi, the only thing that you're missing... is that these don't exist in all wheelbases, hence I didn't use it on my CSW V2.5 wheelbase. go right ahead and use yours!

karelknight, 2021-05-08:
Thank you for your nice and quick answer. :)

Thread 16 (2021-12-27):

Problem with Fanatec DD1 Base

rcalleso, 2021-12-27:
I guess this should work with DD1 base, has anyone tried it?

In my case, when I connect the arduino to the base, the displays turns off, and I have to power off and on the base to start working again. (just the base, the arduino adapter haven't worked yet)

Any clue?

lshachar, 2021-12-27:
Yes, it should work just fine with any wheelbase.
Check your wiring. When you're done, check them a couple more times...
Try to have rather short wires, and make sure there's a good connection on
all the pins.
with my CSW V2.5 I had issues where the wheelbase reset itself (turned off,
then on after a few seconds), which happened because the wheelbase wasn't
happy about the communication it got from the arduino.
It could be that the DD firmware behaves differently in the same situation.
Otherwise maybe you're shortening 3.3V or 5V into ground.

Good luck!

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

rcalleso, 2021-12-27:
Oh, thank you Ishachar!!!!! I was afraid you had abandoned this project :)

I've done two versions, one with connectors, and another one with short wires soldered directly to the arduino, and logic shifter.

Is there any way to be sure the arduino is doing what should be doing??

BTW, your answer is the best Christmas present for me ;)

lshachar, 2022-01-16:
Have the arduino connected to your PC via USB, and start a serial monitor.
If you see a lot of "_____________incoming data crc8 mismatch!________" messages, then your SPI connection to the wheelbase is not working properly. Mine has been like that for the longest time (my PCB was home fabricated and it's really not that good) but if some messages go through, then your wheel should get recognized by the rim and FFB will work. (however I sometimes get erratic double shifts behaviour.)

type c6 and send it (on the serial monitor). you should see a long list of Hex bytes and then "S _ 1" in a new line. this is the message you get on the alphanumeric display when you enter the menu system.
read all the comments in the source code (.ino file), should give you plenty of clues.

 enter the menu by sending c6 to the arduino.

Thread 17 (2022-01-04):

Compatibility with CSL DD

tahir51, 2022-01-04:
Hey, anybody made this project work with CSL DD?

I couldn't get it to work. I double and triple checked the connections but the only thing happened, was the wheelbase turned off. Also got error message on the TM1637 display.

Berstrpriv, 2022-01-06:
So, I am currently also trying this with a csl dd.
My findings so far:
When I attach an P1 wheel in pc mode, then disconnect the wheel, the emulator works. I see a P1 wheel attached, also force Feedback test works.
Now the funny part: my emulator/nano is only connected with 3 wires. Both gnds and the 5v.
In your case, maybe try to set the base into the comp csw2.5 mode. Tell me, if that works cause I don't want to switch wheels everytime i start racing

FixyNeko, 2022-01-13:
Hello
I confirm this project works with a csl DD :thumbsup:
However, this base being brand new and me having no oem wheel, I did encounter some problems : the base was shipped with a version 0 firmware. After upgrading it with the fanatec driver tool, I got both the base and the wheel to be detected.

I ported this project to a RP2040 µC, onnected only one of the two grounds (the one on the outer pins) and used the 3.3V power supply pin.

Berstrpriv, 2022-01-14:
@FixyNeko Thanks for this info. I will give it another go this weekend. Did you also experience random shutdowns when connecting the emulator? Which pins did you use? Mine seem to be too thin.

tahirx51, 2022-01-14:
@Berstrpriv it's probably not the best method but what I did was using male Jumper cables. But they are too thin so you need to thicken them with a little soldering tin. And then try out and adjust until it fits perfectly without play. Also printed a custom SPI 3D Part so the jumper connectors sit tight in them without coming off.

I will give this another try tonight and let you know if I make some progress

lshachar, 2022-01-16:
> I couldn't get it to work. I double and triple checked the connections but the only thing happened, was the wheelbase turned off. Also got error message on the TM1637 display.

what error message are you getting? if you're getting "CRC" then it means the SPI interface is receiving corrupted data on the arduino side. If no packets are transmitted 100% correctly (from the arduino to the wheelbase), then FFB effects will not be enabled on the wheelbase. (the CRC message is generated by the arduino and sent to the display)

If you're getting "UPD" message flashing, then that's better. this message is sent directly from the wheelbase, which is trying to update. This also means your SPI connection is working.
This happened to me quite a lot recently. I just shrugged it off and restarted the wheel. I'm not sure if it was stuck on trying to update the rim (trying to update the arduino code...) which isn't supported and I don't plan on supporting it, or was it just trying to update the wheelbase' and motor firmware, and I killed it mid-way. "UPD" isn't displaying anymore and I just went into fanatec firmware manager (inside Fanatec's driver page, on your PC) and everything is updated to the latest version, (also there's no update waiting for the rim.) So, this is probably not your issue, as you would've just waited or restarted and went on your way. (Your issue probably isn't the best place to write up about this "UPD" issue that I faced, which isn't mentioned anywhere else on this github. oh well).

I currently have lots of CRC8 errors on my PCB, but still able to use the wheelbase.  (see what I wrote here #16 )

(the CRC messages on the alphanumeric display can be hidden, by commenting out #define DISPLAY_CRC8_ON_ALPHANUMERIC. but really you should only do that if it's MOSTLY working fine, and seldomly, every few seconds it recieves a bad packet.)

tahirx51, 2022-01-16:
Thanks for your reply @lshachar. Yes I got the CRC Error. I wired it up a 2nd time with a new level shifter and cables just to make sure there was no faulty connection or soldering. But the outcome was the same. The wheelbase immediately disconnects as soon as I connect the SPI. Almost seems like there is a short circuit and the wheelbase is protecting itself. I did the wiring exactly like in the simplified schematic and didn't use a PCB.

I'm wondering if it may be caused by the jumper cables that I use the pins for the SPI connector (as I don't have a crimping tool). As the jumper cables are very thin and generally not really appropriate for soldering etc.

FixyNeko, 2022-01-16:
I had an issue where I mirrored the pins on the connector. On the wiring schematic you're looking at the wheel side, not the base (I definitely feel like this should be highlighted in this project on the schematic, by the way).
Might be a reason for the base protecting itself and shutting down

smollda, 2022-01-18:
As for contacts, these fit pretty well https://www.tme.eu/en/details/7.010.901.001/m23-connectors/hummel/

Berstrpriv, 2022-01-19:
@FixyNeko
Man, reading this gives me headaches again. I thought about mirroring the pinout way too long.
So, you say that I don't have to mirror anything and just connect it as it's written in the schematic? Because I tried mirroring it vertically and after a few reboots I stopped.

FixyNeko, 2022-01-19:
The schematic is looking at the wheel connector.
What you want to do is putting pins in the base connector. So you have to mirror left<->right

Berstrpriv, 2022-01-19:
@FixyNeko
Yeah alright. Good thing I did that. Otherwise I connect 5v to sclk. That would be massive ouch. Still had these reboots. Need to redo the adapter plug.

FixyNeko, 2022-01-19:
I connected it today in my office (was working elsewhere when I got it working). I have massive issues when I connect anything to the base, more precisely the sck pin is very sensitive and the base shut down (red led slowly blinking). This also happens when I connect only myoscilloscope, very strange. The sck, cs and mosi signals are very good however, they are still sent and no weird tension drop is happening

Berstrpriv, 2022-01-19:
Yeah, it would be nice, if some of the guys with the work adapter could send me their adapter to check on my dd. I am willing to pay. But the currently only available emulator is 100€ without the qr. This is just way too much.

bbogdanmircea, 2022-04-25:
Hello, I could not understand from the discussion if this works or not with CSL DD reliably?
Is there a list of all the Fanatec Wheelbases that are supported by this project?

Berstrpriv, 2022-04-26:
@bbogdanmircea
From what I understand, it is possible with the dd, probably also with podium since all wheels work on all bases, the ffb-check-mechanism has to be the same.
Personally, I stopped trying this. It is not worth it in my opinion. Go for the podium hub. It will be worth it.

lshachar, 2022-04-26:
@bbogdanmircea,
All of fanatecs wheels are interchangeable with all their wheelbases. Because of that reason there isn't such list.
FixyNeko confirmed this works with a CSL DD.

cihaneren, 2022-05-06:
Hello again, I've tried with my CSL DD. I've just needed it for classic steering wheel and I've built the project without buttons or 7 Segment display. Base recognizes Arduino and starts blinking in red. But the driver software of base doesn't recognize the wheel. Should I change something in Arduino code ? Or should I install something more on PC ? (Sorry for noob questions again)

FixyNeko, 2022-05-07:
The base blinks red when an error occured. Did you update the base formware to the latest verzion ? Mine came from factory with a version this project was not compatible with

cihaneren, 2022-05-07:
> The base blinks red when an error occured. Did you update the base formware to the latest verzion ? Mine came from factory with a version this project was not compatible with

Yes, I'm using with my McLaren V2 in latest version. But I've tried to reinstall the firmware manually and it did not help.

lshachar, 2022-05-08:
Connect the arduino to your computer via USB. start a serial monitor. See if the arduino actually gets proper SPI communication with the wheelbase. every line that should be displayed on the LCD screen should also appear on the serial monitor. send C6 on the serial monitor. see if you go into the menu system. read the last comment in [arduino_fanatec_wheel.ino](https://github.com/lshachar/Arduino_Fanatec_Wheel/blob/master/arduino_fanatec_wheel.ino)

cihaneren, 2022-05-09:
Hello @lshachar I uploaded a screenshot of Serial Monitor but I couldn't understand anything from it. I think there is a problem about this.
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

bbogdanmircea, 2022-05-09:
You are not having the same Baudrate set in the Serial Monitor as in the Arduino Sketch.

cihaneren, 2022-05-09:
Now it says "incoming data CRC8 mismatch"... I'll try it with another shifter or arduino :/

Jandako, 2022-08-08:
It does not work for me either on my csl DD...

Balterr, 2022-08-14:
Good evening everyone. Félix FixyNeko How did you run SPI on RP2040 in slave mode?Sorry for my English, I'm from Ukraine.

starter8, 2022-10-07:
Hi. So after bypassing 13pin plug I connected USB C extension to base and connected genuine wheel on the  other side and connected other rim on base. Then I decided to try making emulator and connect it directly via USB port, but I put soldering on hold since pin 3 didn't mach the ground pin. In my findings pin 12 is other ground pin. But decided not to risk it.

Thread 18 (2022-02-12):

Understanding the MOSI buffer

jxweric, 2022-02-12:
Hi everyone, I'm currently trying to add a LED strip as a rev display. Therefore, I have to understand which values in the mosiBuf[] contains rpm values. Can anyone help me to understand the MOSI buffer, which cells contain what information, or is there a list of the MOSI bits information so that I can add other support I might need in the future? Any help is greatly appreciated!!!

Have a great weekend :)

lshachar, 2022-02-13:
[Here's what you're after](https://github.com/darknao/btClubSportWheel/blob/master/dev-tools/cap.py)

As said on the readme file, this project would never have been possible without the work of Darknao on his [BtClubSportWheel - converting any Fanatec CSW steering wheel to a standalone USB version](https://github.com/darknao/btClubSportWheel) project.

StuyoP, 2023-05-29:
Did you made any progress on this? I am doing the same, already added support for rotary multiposition switch and matrix keypad to save some inputs. Already added LEDs but only for backlight, am looking currently to incorporate REV coming from base. It is quite complicated for me to understand the btClubSportWheel project, I see all the information in there but cannot compile it. Also am trying to add support for an APM module - I have a 3D printed design that works very good with a Podium Hub, but I want it supported in emulator to unlock the full potential for my new wheels :)

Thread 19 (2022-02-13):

Teensy 3.2

meggerja, 2022-02-13:
Hello, sorry for maybe stupid question but I would like to ask is this OK to use teensy 3.2 as it's operates at 3.2v instead of arduino with logic shifter?

lshachar, 2022-02-13:
I can't give you a straight answer. I tried to read back on [this huge issue that has lots of good info](https://github.com/darknao/btClubSportWheel/issues/12), and I searched for info in my github, but didn't get anything concrete. If the teensy works properly as an SPI slave, and can keep up with the base clock of the SPI bus at 500KHz, then in theory it should work. But not all boards are born equal and I never tried working with a teensy. Didn't see anyone mentioning getting my code to work with a teensy thus far.

[Sabifa got it to work with a Pro Mini V2](https://github.com/lshachar/Arduino_Fanatec_Wheel/issues/9).
That board can be run at 16MHz at 3.3V and it does work at least to enable FF effects, but I found out that the Pro Mini is not really designed to run at 16MHZ / 3.3V, so I decided not to fully support it here.

Good luck

meggerja, 2022-02-14:
Hello
I found this:
https://www.thingiverse.com/thing:3673632
Do you think it may work?

lshachar, 2022-02-14:
Yes

meggerja, 2022-02-14:
Thank you

meggerja, 2022-02-14:
I'm not sure what do you mean with this center point calibration, this is available threw the pc fanatec software, or maybe I'm thinking about something different 🤔 I've got csl dd so might be different

Kuillemaul, 2023-10-07:
Has anyone made code for the teensy 4.0 as the 3.2 is no longer available.?

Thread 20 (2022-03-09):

Which one is the correct schematic? Easy to understand or simplified?

Shane87F3Ng, 2022-03-09:
Hi Ishachar,

is it possible, that the schematic shown at

https://github.com/lshachar/Arduino_Fanatec_Wheel/blob/master/schamtics%20arduino%20nano-level%20shifter-fanatec%20round%20plug.png

is not correct (anymore?)?

Because you connect the 3V3 from the Base to the 3V3 connector on the arduino, but in your detailed schematics, this connection line is not shown. So which one is right? :)

Cheers Shane

lshachar, 2022-03-13:
Hi Shane,
There is no need to connect the 3v3 on the arduino nano to the low level side of the logic level shifter. Thanks for noticing that. (It was a different user who've made that schematic in the first place!) I will upload that file.

[This is the correct schematic](https://raw.githubusercontent.com/lshachar/Arduino_Fanatec_Wheel/master/Schematics%20%26%20pcb%20layout/how%20it%20looks%20like.png)

Shane87F3Ng, 2022-03-13:
Thanks for your quick response Ishachar :)

A further question, have you ever tried to power your nano board with the 3v3 line from the base to the 5v pin of the arduino? Because at that pin, there is no voltage regulator followed, so digital pin output is also at 3v3. Most of the boards (CH430 clone versions) are actually capable of running at 16mHz at 3v3, as i am using it like that on my Thrustmaster wheel. The positive effect on that is, that no logic level shifter is needed and getting rid of all the noises cause by it.

But i am not sure if the 5v line of the base needs to be used in order to get the wheel recognized

Greets
Shane

lshachar, 2022-03-13:
I've never tried running it like that, (and I suppose that the processor isn't ment to run at 16mhz at 3.3v), but anyways - once you connected the nano to usb, the outputs will go up from 3.3v to 5v. then you're feeding 5v to 3.3v inputs on the fanatec wheelbase side.

Shane87F3Ng, 2022-03-30:
OK, yeah tomorrow i will have time to solder everything together. Does anybody know, If i need all 13 Pins or can i just go with 8, that are actually used?

lshachar, 2022-03-30:
...What would you solder all the unused pins to?
Obviously you don't need to solder them.

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

Shane87F3Ng, 2022-03-30:
I mean not to solder them, but are they necessary in a way, that the base can detect the pin contact. otherwise i would just go with 8 Pins, you know what i mean?

ProjectCoops, 2022-04-19:
Hi Ishachar great project, i have and original pcb csl elite p1, i would like to cut the pcb board down for a drift wheel and require no buttons,
1. MISO
2 .MOSI
3. GND
4. 5v
5. GND
6. SCK
7. 3v3
8. CS
Could you please tell me which of the first 8 pins are necessary for the wheel to be detected for ffb, i can calibrate via fanatec properties.
Thankyou.

lshachar, 2022-04-19:
All of them.

Closed 2022-04-06.

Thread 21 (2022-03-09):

>Implement Buttons and encoders

Shane87F3Ng, 2022-03-09:
Any help / hints on that?

Hello @lshachar,

first of all, thx very much for your work, that is just awesome!
I have one question about how to add additional buttons / encoders..
Do i need to change to another wheel than the Porsche RSR? or just modify the button matrix and bytes?
Because as far as i know, i can only use buttons that are originally supported by the wheel? it is like that with thrustmaster

Actually i build sth similar for my previous thrustmaster base and was reading the wheelstates with an arduino sketch by https://rr-m.org/blog/ to implement it into my sketch and simulate the right wheel..

my plan is to use:

3 encoders  + push button
8 buttons

so in total i would need to have 19 buttons (wheel states)

any help on where to start?

@EtienneGameSeed As is saw you do not sell the teensy anymore, maybe you can help with some thoughts here without getting too much info away on your own project.

_Originally posted by @Shane87F3Ng in https://github.com/lshachar/Arduino_Fanatec_Wheel/issues/12#issuecomment-1060968563_

Shane87F3Ng, 2022-03-12:
OK, i figured it out :)

lshachar, 2022-03-13:
I think your assumption will turn out to be true - you should figure out which of the fanatec wheels supports all of your wanted 19 buttons (check out the fanatec universal hub as well), because it sounds feasible that any wheel will only support buttons that should physically be on it.
once you have your answer, it's very easy to change the wheel byte in the arduino code, as you probably have found out by now.
Start off with changing some button bytes and noting that the button states in fanatec's driver (or in a game / other joystic utility) is actually changing.
The rest should follow easily!

Shane87F3Ng, 2022-03-13:
Nice. I will try a setup with a button matrix and report back as soon as i have results :)

lshachar, 2022-03-13:
At first you don't even need a button matrix. There's a way to toggle bits on and off using the serial interface. look it up in the code and try flipping some bits that are used for buttons. they should toggle in the controller driver application

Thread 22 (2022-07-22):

Holding pressed any button it operates repeatedly

fsgroppo, 2022-07-22:
Dear Ishachar

First of all my congratulations for this project, your work makes this community benefit by adding value and facilitating access to knowledge for all of us who started in this type of project. Congratulations again.

Issues = I followed your instructions to the letter and put together this adapter for a Fanatec CSW 2.5 base. It works almost flawlessly except for two details;

a. when the adapter is in use (after base calibration, up and running) the TM1637 display correctly shows the chosen gear (in game) in the second segment, but randomly and for a very brief moment it also shows in the third segment; there seems to be some problem sending data from the arduino to the TM1637 display. This happens all the time, regardless of the information that the display must show; in fact it doesn't matter if you are in a game or not, the display shows a blinking in the third segment randomly.

b. I have found that by holding pressed any of the gear shift levers (I use the arduino A1 and A2 outputs) the gear changes occur consecutively in ascending or descending order depending on which lever you press; example: I press and hold the lever to shift up and the gear shifts from neutral to 1 and after a very short moment it continues to shift up 2, 3, 4, 5, and 6 (without releasing lever) when it should just shift from neutral to 1 no matter how long you keep the lever pressed. This operation that I describe causes that when you are racing inadvertently two consecutive gears are raised or lowered.

So my question to you is if it is possible to change any parameter or line of code to resolve a. and b. (especially b., which is the most important). I have no programming knowledge, but if you could tell me which line of code and which values   to test I would be closer to finding a solution to these issues.

Thank you, greetings from Argentina.

lshachar, 2022-07-22:
Hi @fsgroppo, and thanks for the kind words :)
connect your arduino to your computer via USB and start a serial monitor. I'm guessing that you will see "incoming data crc8 mismatch!" warning messages popping up on the monitor. This explains why your gears are bouncing as well as the display faulting.
If I'm right, please look around in the other opened and closed issues here about how to fix the crc8 mismatch problem. basically, it's difficult to get a good SPI connection between the wheelbase and your arduino because the wheelbase is very sensitive to interferences.

fsgroppo, 2022-07-22:
Thanks for your answer. I attach what I get through the serial monitor (it's the very first time I use it). I don't understand anything at all, any suggestions?

Greetings
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
.

lshachar, 2022-07-25:
Change the serial baudrate to 250000.

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

fsgroppo, 2022-07-25:
Dear Ishachar.

Thank you for your reply. Now I have managed to get more consistent information, I attach the image in case you see something that is relevant and I can not interpret. You were rigth about CRC8 errors; occur persistently without the need to press any button. I have read about each of the problems exposed here and the way to solve my problem would be to try to correct the possible interference problems that you have mentioned. Doing this implies manufacturing a completely new adapter in my case because I have strained with epoxy resin all the components (conductors, arduino, logical level, etc.).

Then... I go with my last attempt to consult you whether or not it is possible to do something or try something different with the code, of course I repeat I do not know what statements like these do:

delayMillis = 400
dataLength 33
lastPrintMillis = 0

but if it occurred to you to try something different with these values or explain to me what these values define I could make one last attempt before discarding the adapter I already made and having to make a new one directly addressing the necessary changes to avoid interference.

Thank you very much for your attention and take care to dispel my doubts.

Greetings
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
.

lshachar, 2022-07-26:
Your adapter looks really really nice!
The code isn't the issue, and there should be nothing that you could change that would help..
It's a game of having large ground pads everywhere possible, and good contacts on all your SPI signals, But it's just not easy to get it working very well.
You can try using a genuine arduino as well, that might help.

One option that comes to mind is - use another arduino (such as arduino pro micro) to connect all the buttons to. run its line outside of the steering wheel with a flexible cable. have it connected to your computer.
Having that second USB cable is kind of annoying, but also trying to get good SPI communication with the wheelbase...

fsgroppo, 2022-11-09:
Dear ishachar

I have made a completely new emulator (all new hardware too) following your advice, I am attaching some photos illustrating the work. Unfortunately I still have the exact same problem. There is no other thing else that I can do. I plan to try to remove from the code - and I don't know exactly how to do it, it will be trial and error - the features that I don't need just to make the code shorter, but I'm sure it won't solve the problem either. when I say remove from the code I mean not to comment the line of code with //, but to delete it from the code completely. I don't need the display, I don't need the dpad. all I need is x2 buttons to actuate the gear paddles. After this... it will be time to leave the project with a bittersweet taste if it does not work. I congratulate you for the work you have done. A big hug from Argentina.

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

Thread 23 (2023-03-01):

The steering wheel randomly enters menu mode

devActive527, 2023-03-01:
Thanks for your work! The whole work is great, but for me, after some time of playing, the steering wheel enters the menu by itself. I don't have a d-pad (commented), but I see the s5 on the display after some time. I wonder what is causing it. It's probably due to interference. I was thinking maybe add an extra 'if' in the buttonBitChange() for bit 22 - I don't need menus and calibration, I have a different steering wheel.

lshachar, 2023-03-17:
Hi Paul,
I had a similar issue, until I changed my arduino, logic shifter, and switched to a properly manufactured PCB from jlcpcb, instead of the one that I originally hand crafted from a perforated pcb.
The necessary manufacturing files are [here](https://github.com/lshachar/Arduino_Fanatec_Wheel/tree/master/Schematics%20%26%20pcb%20layout/KiCad/Gerber).
You are entering the menu because the wheelbase reads some faulty bits on a packet that is sent out from the arduino. So you are not going to find any workarounds in the current code.
Other than fixing your hardware, it is possible to write a piece of code that exits the menu (by sending out the right button byte) every time that the arduino recognizes that the menu is on when it's not supposed to be.
I updated the code 3 months ago (on the master branch). this shouldn't fix your issue but try updating yours if you haven't already.

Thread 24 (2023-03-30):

Using PIC Microcontroller

StuyoP, 2023-03-30:
I know it is far fetched, but worth asking if somebody has done it.
As this great project is using SPI in its core I presume utilizing a PIC Microcontroller would seem feasible. I have some experience with configuring PIC 16F690 to use as Fanatec shifter emulator and presume for here it would be also applicable. This PIC can be powered with 3.3V, has 18 I/O ports, supports SPI and works at 20MHz.
Issue is I am pretty bad as developer and am wondering if somebody worked already on that. I can program the pic to the part that it is SPI Slave and which ports are used for what kind of communication, but the rest is to splice the actual serial communication code from here.

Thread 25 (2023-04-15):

Other wheels reference IDs

Alexbox364, 2023-04-15:
Hi everyone,

first, thank you very much for sharing this very good code basis to interact with Fanatec bases!  I had it up and running quite fast and SPI implementation is great!

I'm working on a project to build a custom wheel based on a Podium hub and the fantastic Turn 911 GT3 R 2023 DIY wheel (freely available build up files) (custom wheels based on USB cables or Bluetooth communication did sound a good option to me)
https://www.thingiverse.com/thing:5702348.

As a first step, I tried to find out which Fanatec wheel to replicate to have so many buttons so I tried to identify other wheels and their associated ID in the SPI protocol. Here is the extended list I build :

{0x01} for BMW M3 GT2,
{0x02} for ClubSport FORMULA,
{0x04) for Uni hub
{0x05} X
{0x06} universal hub hub xbox one
{0x07} CSL elite p1 xbox
{0x08} CSL P1 v2 - FW update required
{0x09} Maclaren GT3 v1
{0x0A} clubsport formula v2 / v2.5
{0x0B} Maclaren GT3 v2
{0x0C} Podium hub
{0x0D} not supported
{0x0E} Bentley - FW update required
{0x0F} Podium M4 GT3
{0x10} X
{0x11} CSL universal hub
{0x12} CSL elite WRC
{0x13} BMW GT3 v2
{0x14} X
{0x15} CS universal hub v2
{0x16} CS wheel f1 esports v2
{0x17} Podium BWM m4 GT3
{0x18} and above - nothing

I discovered by the way the so good looking Bentley Fanatec wheel!

For some wheels, my DD1 base required a wheel firmware upgrade to work.

I hope it can help others build their own wheel. I'll post updates here if I can help others.

cheers

StuyoP, 2023-05-22:
Hi,
Thanks for this list, it will help me greatly in my next project!
I actually already build the Bentley wheel, but am driving it with USB and SimHub :)
Did you make any progress on the other wheels? I am looking into building something that support rotary positional switch (something like the F1 toggle rotaries) in order to use as MAP dial. Also wondering if APM module is possible to be interfaced as I already build custom 3D printed one that works great with the original Podium Hub.

Thanks!

StuyoP, 2023-05-30:
Hi mate,
Thank you very much as well! The servo one is great, but I had a servo die on me after a year of heavy use, switched to the SimHub native stepper motor one (as myself also cannot anymore without belt tensioner). Working on video and written review ATM, feels better and is quieter.

About the Fanatec emulator - I moved quite ahead already. I made it work powered from base, added keypad matrix to save some pins, added rotary switch voltage dividers and translated them in code to button press, added initial aRGB support. I am currently wrapping up the Ford Puma WRC Wheel button plate and all three rotaries work, together with 9 buttons. Have total of 13 buttons coming from default profile and am 1 button short so wanted to move to another profile. Substituted the OLED screen with a 3 digit 7 segment, looks pretty good for the time being.

Already ordered some ATMEGA329P chips and will make a barebone version as well at some point and will hopefully make it work at 3.3V to ditch the Level Converter. I suck badly at programming and struggling currently to implement dual clutch so I can add my APM module and make the Bentley wheel natively supported. I can incorporate the LED matrix to show speed but for the most advanced features it would not be possible to make them native.

I went through the original emulator code - most of it is already there. Also clutch, additional paddles, REV LEDs, and one rotary - this is the standard supported SPI, but as I said - I suck at programming and have issues isolating the code and transferring it here.

I am documenting everything and will make extended material how all was assembled. Pretty happy with this project, it unlocks quite a potential for all my other wheel projects.

As far as the other "advanced" features go - they are not part of the standard SPI and I doubt they are there. Most probably the are additional controllers which communicate through the additional pins (the ones for the advanced Porsche module) or additionally encoded somehow in the original SPI package (less probable option). I have the basic skills to start monitoring and decoding, but not much free time as am pressing the other projects. In general if this is supported by the reverse Fanatec emulator which is the base for the code here it should be pretty straight forward to extend.

You can find me in the Discord channel of the site where we can discuss further. I have another member there and we are struggling together to push forward this project :)

Hope together we will manage to extend it even further!

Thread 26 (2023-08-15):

CSL DD wheel base connects and discconects with wheel attatched.

thomaswang04, 2023-08-15:
Hello everyone, sorry if this is a stupid question but i was able to get the wheel wired up the only way i've  been able to get it to work is by having the Arduino powered up before turning the wheel on. Otherwise when the wheel starts up it instantly disconnects after start.

lshachar, 2023-08-15:
It's not a stupid question, but it is lacking information. I'm not sure if your arduino is properly powered from the wheel once the wheel starts. If you followed my diagram, there's a diode so that you're not powering the arduino from USB while also powering it from the 5V pin connected to the wheel. the diode is there so that the power supplies on the wheelbase do not get voltage from the PC's power supply.

mbakos82, 2023-08-28:
Hi. I have the same problem. When my Arduino is plugged in to USB before I plug it into the wheelbase, the steering wheel is detected. Otherwise the wheelbase disconnects. I also found out that when there is no wheel plugged into the wheelbase, I measure voltage across the 5V pin and any of the GND pins, there is no voltage at all. Maybe the wheelbase powers on the 5V pin after SPI comm is established. It might be something else totally. My test scenario is a Nano with level shifters and a bush of wires on a breadboard.

lshachar, 2023-08-28:
That's an interesting find! see if the 3.3v line is always supplied once you turn the wheelbase on, and see if the 5v line is off at the same time. then see if the 5v line turns on after spi comms is established.
(have the arduino running from an external 5v supply, and have a common ground connected (between the arduino and the wheelbase. then you can measure the 5v line externally with a multimeter to see at what time it turns on)

If the wheelbase behaves the way I described, then it means that *all* of fanatec's wheels must be running from the 3.3v line, with the 5v probably only there for peripherals (or never used). and it would also mean that anyone with a CSL DD wheelbase would either need to add a 3.3v to 5v step up converter (boost converter) to power the arduino nano from, or completely change the nano for a 3.3v board. There's some information about this in other issues and [in this pull request](https://github.com/lshachar/Arduino_Fanatec_Wheel/pull/13)

mbakos82, 2023-08-28:
There are some more crazy things happening in the wheelbase without a wheel connected.
After turning on the wheelbase (no wheel connected), I measure 3.16V on pin 3 compared to pin 5. (Both should be GND.) On pin 7 (3.3V pin) I only measure 0.3V. Then I connect pin 3 and pin 5 through a 10 ohm resistor, 2 things happen. 3.3V comes alive on pin 7 and the wheelbase disconnects. Pin 7 remains live after I remove the resistor. Pin 4 (5V) comes alive as well.

I tried connecting the wheel with arduino 5V power only. The wheelbase 5V pin comes alive immediately when I connect the arduino to SPI.

thomaswang04, 2023-08-28:
Could it be that the fanatec wheels are getting power from one of the other pins that are unused? I looked online and it looks like pins 9 and 12 are used as a usb pass through for power and ground. I will try and check those pins when I get the chance

mbakos82, 2023-10-06:
Hi again. I have come across a new theory after letting my frustration settle a bit. On the original wheel connectors, one pin is shorter than all the rest. Has anyone wondered why that could be? My theory is that when you connect the wheel to the base, the GND pin on the outer rim is connected a tiny bit later than all the rest of the pins. It is when the 2 GND pins are shorted inside the wheelbase, SPI packets are beginning to be sent to the wheel. By fully plugging in the adapter, that very short timeframe could be required to boot up the adapter to a state that it is ready for SPI communication.
I have taken my adapter apart already, I haven't had the chance to test this idea.

I would be interested in how many people have taken care of making that one pin shorter and how does it relate to the success of their project.

lshachar, 2023-11-09:
I remember starting to reply but apparently never sent it. No I would not think that the shorter pin is relevant. these are pogo pins (spring inside) and maybe it got stuck pushed in. or a manufacturing defect. a drop of wd-40 might release it. however I'm rather sure it's not intentional or serving a purpose.

@thomaswang04  everything is possible, I researched a different wheelbase when the CSL DD did not exist yet.
However, since my arduino wheel works very reliably on my CSW V2.5, I'd expect it to work the same on other wheelbases too.

irisnotaprogrammer, 2023-11-09:
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

I can confirm this works on a CSL DD GT Pro as well.  Succesfully made this project for mounting a truck wheel to my Fanatec base.

For some information: I used an Arduino Uno with a level shifter, because that was what I had laying around, except for the level shifter :P .

Base powers up as it would with an actual Fanatec wheel.

As for there being pins that might behave different: given that there are wheels with OLED screens in them, I suspect that they might act like a small DisplayLink device and need USB communication that way.

irisnotaprogrammer, 2023-11-21:
> ....and just stop having all sorts of weird wiring issues...
If you would see my home-made connector on the Fanatec base for extending it to the truck wheel along with what the test setup looks like you would understand that it's probably down to people misreading the schematic or not providing good joints (I am on a Discord server where people try to use taped together wire joints...)

> btw I'm quite disappointed with how nobody respects the fact this project is a donationware. :/

Let me make that up ;)

By the way, are button matrixes possible?  I am currently not exactly out of button pins and the addition of buttons that there could be would be up to 4 extra of the 5 I already use so there are definitely pins left on the Uno, but I was simply curious.

thomaswang04, 2023-11-21:
> By the way, are button matrixes possible? I am currently not exactly out of button pins and the addition of buttons that there could be would be up to 4 extra of the 5 I already use so there are definitely pins left on the Uno, but I was simply curious.

I assume as long as you can program it it will probably work

lshachar, 2023-11-23:
@irisnotaprogrammer
> Let me make that up ;)

This made me very happy, thank you! I really appreciate it :)

> By the way, are button matrixes possible? I am currently not exactly out of button pins and the addition of buttons that there could be would be up to 4 extra of the 5 I already use so there are definitely pins left on the Uno, but I was simply curious.

Yeah as @thomaswang04 said, it's just a matter of programming it, and it should be very straightforward. the only limitation would be the size of the button byte array, which is either 22 or 24 buttons. (as the last comment in [arduino_fanatec_wheel.ino](https://github.com/lshachar/Arduino_Fanatec_Wheel/blob/master/arduino_fanatec_wheel.ino) says)

> (I get that it might feel uncomfortable, but you could hide a part of your project behind a payment. It's definitely not foolproof, but still).

Nah, not for me. thanks for the thought though! :)

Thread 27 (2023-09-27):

CRC8 Mismatch and low voltage on L1/H1 pins

minnis23, 2023-09-27:
Hi, I'm attempting this project without the screen or buttons (I've got another solution for this).
The wheel isn't working, and opening up the serial monitor I am getting the CRC8 mismatch error.
I have looked at my connections with a multimeter - on both sides of the logic level shifter, I'm getting 3.3v and 5v for all pins except L1 and H1, where I'm getting about 0.2v. I presume this is the issue, or is this pin meant to be low?

lshachar, 2023-09-27:
You are reading digital lines with a multimeter. Which tells you nothing. If you want to see whether the data is really transmitted properly - you need an oscilloscope.

minnis23, 2023-09-27:
Okay - I thought that the point of the logic level shifter was to transform 3.3v inputs to 5v and vice versa, as it is with the other pins - is this not the case with L1 and H1 then? I don't have an oscilloscope - is there any other way to confirm using just a multimeter, even if it's ruling out that all _other_ connections are okay? All LV pins show 3.3v and all HV pins show 5v (bar LV1/HV1 as mentioned above). I had initially forgotten to add a 5v line to the arduino but I have corrected that and the arduino is now getting 5v. Of the 4 pins on the arduino, the power and TX LEDs are bright, the RX LED is off, and the "L" LED is showing vague signs of wanting to flash but isn't properly lighting up. Does this point to anything in particular? Apologies if any of these are rather silly questions - I've done several projects with arduinos before, programming them through Simhub, but this is the first time I'm attempting something more complex.

minnis23, 2023-09-27:
Just for extra info.
At no point does Fanatec control panel recognise the wheel.
If the wheelbase is turned on, I will hear the Windows "disconnect sound" as soon as I attach the wheel and the wheelbase will disconnect. Simply removing the wheel isn't enough to sort this, I need to remove the wheel and turn the wheelbase off and then back on.
If the wheelbase is turned off, upon turning it on I'll be met with the Windows "connect sound" followed immediately by the "disconnect sound" and the wheelbase (but not the wheel) will momentarily flash up as connected in the Fanatec control panel before disappearing again.

bananafrog, 2023-10-07:
Hi, did you end up finding a solution? I have the same problem on my pro micro. I'm going to try wrapping a ground wire around the data pins, as that what I've seen on other threads

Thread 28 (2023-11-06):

Wheel keeps disconnecting in Control Panel and no Buttons etc. work

janmannsbart23, 2023-11-06:
Hey all,

I'm currently working in an STM32 implementation.
I'm using a SPI DMA Slave for communication and wanted to try in the first place if the wheel is detected in the software and button presses are recognized.

I've used the data paket as mentioned in your sketch.

The wheel is also recognized in the Fanatec Software, but periodically disconnects for a second and then reappears.
I also tried to set some button bits (like in the image), but nether of those were recognized in the control panel.

I've captured the communication with an analyzer, but as far as I can see and understood the protocol, this should be fine

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

I also cannot see any abnormalities watching the communication over a longer time, that might explain the short disconnects of the wheel.

Any help would be very much appreciated.

janmannsbart23, 2023-11-06:
For completion:
Im on
CSL DD
PC Driver 451
Wheel Base: 1.1.85
Wheel Base Motor: 1.0.3.2

lshachar, 2023-11-09:
Hi @janmannsbart23,
See if you sometimes get a text on the alphanumeric display data bytes. I wonder if the text is something like 'UPD' which means that the wheelbase is trying to get the wheelbase to update, which it cannot with my code.
For me (CSW V2.5) when that text appears it flashes, so it won't appear in all data bytes, so set up your way for catching it appropriately.
For me it's not an issue and the wheelbase doesn't try to update the wheel every time, only once every idk 20 times I plug in my controller. but I'm wondering if the CSL DD tries to automatically disconnect and reconnect the wheel to update. and then you might be getting the disconnects. just a thought.

There is something fishy with the CSL DD. if you go through the issues tracker you'll find quite a few issues relating to that wheel. you owning a scope and actually knowing your way around SPI coms, puts you in a great place to actually solve the problem. I think you might gain some insights from other people's posts about the CSL DD.

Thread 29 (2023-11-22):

Problem to convert from STM32F4

Lopinhos, 2023-11-22:
Hello Ishachar.
I'm having trouble converting the program to the STM32F4.
I'm still very inexperienced in programming, even more so something created and complex.
I was wondering if you could give me a hand with this question!
In the image there are the initial errors that appear to me, but after defining the pins other errors appear, and after that error it goes back to the lines in red
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

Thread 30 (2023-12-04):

Confirmed working: CSL GT Pro, Arduino Uno and level shifter

irisnotaprogrammer, 2023-12-04:
Ischachar, in case you don't want confirmed builds for wheelbases other than the one your guide focuses on you can close this or remove it since it's not an issue.

For anyone with a CSL GT Pro and is wondering whether or not this tutorial works for that wheelbase: it does.
I have made one with an Arduino Uno, and a level shifter.  The level shifter piggybacks on the Arduino's header pins and uses a DIY'd piece of lane PCB for this, as you can see in the pictures.

It carries 6 direct buttons, and a D-pad with a center-contact (pushing down) that came from an old television, a D-pad I hope to use to navigate game menu's with.
This is all meant to make the wheelbase have Force Feedback because of the Volvo truck wheel attached to the base (through a piece of steel pipe going through a barrel-ball-bearing assembly 50 cm's away from the wheelbase quick connector) because the truck wheel weights around 2,5 kg which I considered to be a bit much).

5 Of the buttons on the Arduino are the 4 cruise control buttons (cruise control on, resume on the left, and increment and decrement the speed set on the right) and the horn button (interconnected, I have thought about making them distinct in order to trigger different types of horns for the games that have this support)
The D-pad is on the underside of the right cruise control button module, and was not originally there in the wheel.

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

The D-pad required changing the line in code from INPUT to INPUT_PULLUP because values where otherwise to close together.
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

wegreenall, 2023-12-13:
I have been looking at doing this for my CSL DD as well. However there seem to be lots of pinout diagrams and it's a bit confusing. Given that you have got this to work, could you clarify the pinout of the wheelbase so I can work out exactly what to plug in where? my 5v seemed to be on a different pin and of course I might just be being dumb about it, but it'd really help to get clarification from someone who has definitely done it on a CSL DD.

irisnotaprogrammer, 2023-12-16:
Can I ask you if you happened to make the mistake of not mirroring the pinout?  Because I probed it with a scope and it is exactly the same as it is in the tutorial that Ishachar made, but a common mistake to make when not working electronics much can be to forget to mirror any images.
(And even if you are experienced, missing the "PIN LAYOUT - BOTTOM VIEW" in a datasheet can cause you to scratch your head for hours until you realize you were not looking at some of the pins in the required order).

When I looked at this picture and the left connector:
https://github.com/lshachar/Arduino_Fanatec_Wheel/blob/master/schamtics%20arduino%20nano-level%20shifter-fanatec%20round%20plug.png

I found out the connector inside my Fanatec wheel (the simplest you get with one of the bases, the previous owner probably used a different base before switching to this one) has 1 pin extra and while unpopulated, the pinout seemed to differ a bit (difficult to know for sure since it has all kinds of interconnections with capacitors, so I didn't trust that to much during probing with a scope).

As a result I followed the pinout on the right part of the picture, and made sure to mirror it (since you will be working on the back of it basically, so it is practical to have the pinout like you are looking at it, and not from the side you can't see when plugged in.
I followed the drawn diagram (I will add  it can throw you off easily due to the mixed colors and mixed numbers especially on the left side of the picture holding the surface-mount angled connector) behind the level shifter to connect the right wires to the right inputs on the Arduino, and got it to work that way.

So best to check first: did you happen to measure 5V on what appeared to be pin 5 because you didn't flip the picture?

(And before you want to feel stupid: my brother designed and etched a whole PCB once for a power supply he was making, and etched the control chip with all the pins inverted for thinking he was having a top-down view during design, and because he get's confused when doing bottom-layer etching toner-transfer prints, he tends to accidentally flip his design).

wegreenall, 2023-12-16:
I thought i had but perhaps I was just getting confused - i just thought i
would ask for confirmation! I will use that diagram in that case. Thanks!

On Sat, 16 Dec 2023, 21:54 irisnotaprogrammer, ***@***.***>
wrote:

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

irisnotaprogrammer, 2024-01-09:
The code by the way allows combining libraries!  In my project, the Volvo wheel that I use has horn buttons in thumb-positions at 9 and 3 o clock.  My hands are a bit on the small side to reach them easily, and I have found that trying to rotate my hand inwards toward a horn button while trying to also keep in contact with the wheel makes me go in a different direction more easily than just taking my hand off and pressing the middle of the wheel (which doesn't have a button).

I decided to use the ADCTouchSensor library by Alexander Pruss to turn the metal Volvo logo into a horn button:
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

I unfortunately had my hand over the microphone of my phone, so it is difficult to hear, but here is the "button" in operation:
https://github.com/lshachar/Arduino_Fanatec_Wheel/assets/143168797/33b623da-c032-4317-bc88-c264d340d14b

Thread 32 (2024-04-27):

Yet another CRC8 issue

johnysed, 2024-04-27:
Hi, so Im doing just the ffb unlocker and I can't get it to work.
There Is like 98% CRC8 mismatch lines. I shielded everything, checked the connection, etc. Any other possibility?

Im using arduino Pro Mini without bootloader. Connected directly, as it is 3,3V.
Everything is connected as in your schematics, except for the 5V pin from the base, I don't connect that at all.

I managed to get it running like twice, but no luck otherwise.

Thanks for any help

lshachar, 2024-05-01:
way to go for getting it working!
what was it that resolved your crc8 mismatch issue?

I can't tell you what's not working. did you get to try it with a proper fanatec steering wheel?
Open the run command window:
win+r
type:
joy.cpl
do you see your fanatec joystick there?
double click it
do you see a steering wheel connected or just a wheelbase?
can you start the ffb test or is it not available?

oh, now that you have crc8 matches, try to comment all serial communication messages and see if that makes a difference (in case you still cannot use your wheelbase yet)
I've had an issue with slow response from buttons (that are installed on my rim) and that was the culprit.

johnysed, 2024-05-01:
Thanks for your comments, it seems like the 3V3 8mhz is not enough, or not sure.
I did your version with 5V 16MHz and logic shifter and that works flawlessly.
I'll try to poke in it again, but probably will just go the route of the logic shifter.

lshachar, 2024-05-05:
oh yeah, I wouldn't expect it to work at 8mhz. github is hiding your edits very well, I didn't see that information before. you can try going the stm32 way, to get 3.3v & over 16mhz in one board.

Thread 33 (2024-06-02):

ESP32 Inconsistent Connection

hickmanz, 2024-06-02:
Im trying to get this code to work on an ESP32 and have frustrating results.  Occasionally it connects and works exactly as intended.  But most of the time, it seems to crash the wheel base (CSL DD) and I need to power cycle the wheelbase.

I also have experienced it working fine, temporarily the computer losing site of the wheel base and then it returning again.

Below is the code I am using to get basic functionality going.  I have stripped out almost everything except the emulation of the wheel while I try and solve this problem:

`#include <Arduino.h>
#include <SPI.h>

#define CS_PIN 5
#define DATA_LENGTH 33

uint8_t returnData[DATA_LENGTH] = {
  0xA5, 0x03, 0x00, 0x00, 0x00, 0x00, 0x00, 0x00, 0x48, 0x83, 0x87, 0x47, 0x7B, 0x9A,
  0x79, 0xA0, 0xC9, 0xB5, 0xD8, 0x1D, 0x72, 0x20, 0x2C, 0xFA, 0x62, 0xFF, 0x93, 0x04,
  0xCB, 0x98, 0xD0, 0x12, 0xAF
};
volatile uint32_t sequence = 0;

void cableSelect();

void setup() {
  pinMode(CS_PIN, INPUT_PULLUP);
  SPI.begin();  // Initialize SPI port
  SPI.setDataMode(SPI_MODE1);  // Set the SPI mode to mode 0
  SPI.setBitOrder(MSBFIRST);  // Set MSB first for data order
  attachInterrupt(digitalPinToInterrupt(CS_PIN), cableSelect, FALLING);  // Attach interrupt for CS pin
}

void loop() {
  // Since the SPI transactions are handled in the ISR, the loop can remain empty
}

void cableSelect() {
  if (digitalRead(CS_PIN) == LOW) {  // Check if CS is low
    for (sequence = 0; sequence < DATA_LENGTH; sequence++) {
      SPI.transfer(returnData[sequence]);  // Send data back to master
    }
  }
}`

I am running out of things to try next and the inconsistency of working vs not working is making it hard to troubleshoot.

Yannicflight, 2024-12-30:
Your problem might be power related as the esp32 is more power hungry then a Arduino.

Try supplying the esp with an external 5V source to test, make sure to common ground them!

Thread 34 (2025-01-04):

Hi can someone tell me which drawing is the right drawing to make the nano emulator with plz

J3161, 2025-01-04:

lshachar, 2025-01-05:
This is the full schematic
https://github.com/lshachar/Arduino_Fanatec_Wheel/blob/master/Schematics%20%26%20pcb%20layout/Legacy%20layouts/how%20it%20looks%20like.png

and this version just to get ffb working
https://github.com/lshachar/Arduino_Fanatec_Wheel/blob/master/schamtics%20arduino%20nano-level%20shifter-fanatec%20round%20plug.png

J3161, 2025-01-05:
Hi ishacher  so this will work on ps5 when I make the emulator I just want access to all buttons to create my own wheel

J3161, 2025-01-05:
Hi ishacher if you can explain me In Step by step on how to make the nano emulator I will pay you petrol money

J3161, 2025-01-06:
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

Hi ishacher I got it working with the fanatec ffb diagram but emulator keeps glitching with numerous buttons. I want to use buttons is there another code I need to download or is your Arduino ino file the right code. Thanks

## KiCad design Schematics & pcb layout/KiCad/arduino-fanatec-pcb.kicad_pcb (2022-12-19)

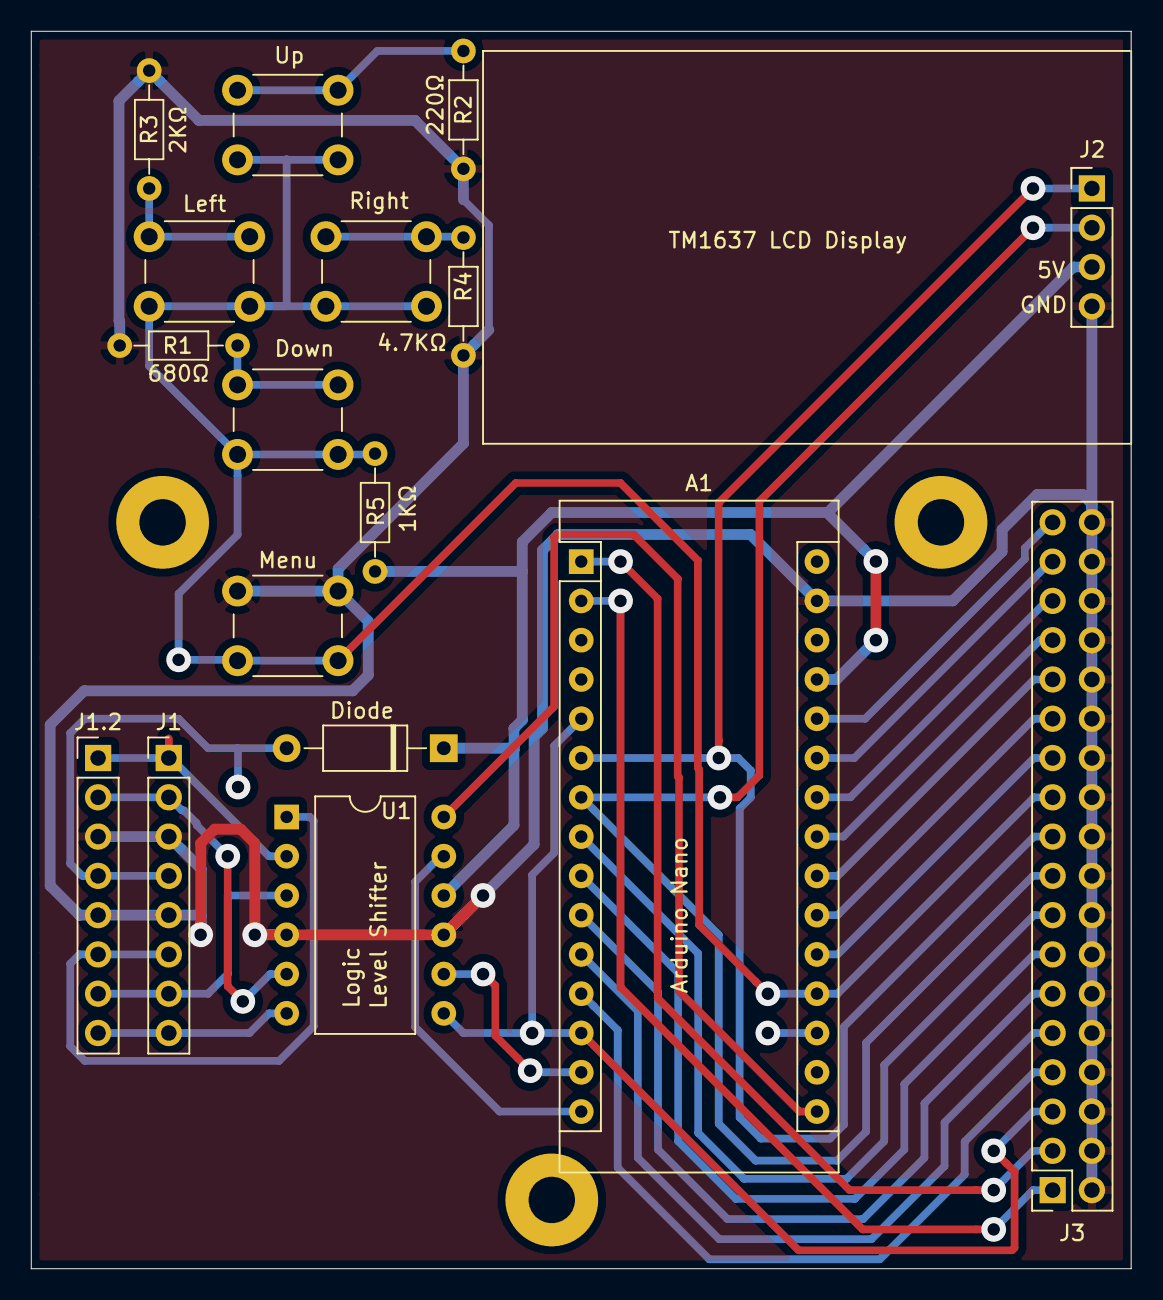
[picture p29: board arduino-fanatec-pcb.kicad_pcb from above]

Board: 2 copper layers, 71.1 x 80.0 mm, 20 parts (0 on the bottom side), 33 nets.

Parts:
A1: Arduino_Nano_v3.x; Arduino_Nano
Diode: .; D_A-405_P10.16mm_Horizontal
Down: SW_Push; SW_PUSH_6mm
H1, H1#2, H1#3: MountingHole; MountingHole_3mm_Pad
J1: SPI Connector 01x08_Male; PinHeader_1x08_P2.54mm_Vertical
J1.2: Extra pin breakout; PinHeader_1x08_P2.54mm_Vertical
J2: TM1637 4 digit Display connector; PinHeader_1x04_P2.54mm_Vertical
J3: Breakout Connector 02x18_Odd_Even; PinSocket_2x18_P2.54mm_Vertical
Left: SW_Push; SW_PUSH_6mm
Level Shifter: Simple_Chinese_Logic_level_shifter; DIP-12_W10.16mm
Menu: SW_Push; SW_PUSH_6mm
R1: 680; R_Axial_DIN0204_L3.6mm_D1.6mm_P7.62mm_Horizontal
R2: 220; R_Axial_DIN0204_L3.6mm_D1.6mm_P7.62mm_Horizontal
R3: 2k; R_Axial_DIN0204_L3.6mm_D1.6mm_P7.62mm_Horizontal
R4: 4.7k; R_Axial_DIN0204_L3.6mm_D1.6mm_P7.62mm_Horizontal
R5: 1K; R_Axial_DIN0204_L3.6mm_D1.6mm_P7.62mm_Horizontal
Right: SW_Push; SW_PUSH_6mm
Up: SW_Push; SW_PUSH_6mm

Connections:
/5V: A1.27, Diode.1, J2.3, Level Shifter.11, R5.2
/D0: A1.2, J3.1
/D1: A1.1, J3.3
/D5: A1.8, J3.15
/D6: A1.9, J3.13
/D7: A1.10, J3.11
/D8: A1.11, J3.9
/D9: A1.12, J3.7
/D10: A1.5, A1.13, J3.5, Level Shifter.7
/Dpad: A1.19, Down.2, J3.21, Left.2, Menu.2, R5.1, Right.2, Up.2
/TM_CLK: A1.6, J2.1, J3.19
/TM_D: A1.7, J2.2, J3.17
GND: A1.29, J1.3, J1.5, J1.2.3, J1.2.5, J2.4, J3.2, J3.4, J3.6, J3.8, J3.10, J3.12, J3.14, J3.16, J3.18, J3.20, J3.22, J3.24, J3.26, J3.28, J3.30, J3.32, J3.34, J3.36, Level Shifter.6, Level Shifter.12, Menu.1, R1.1, R2.1, R3.1, R4.1
unnamed: A1.14, Level Shifter.8
unnamed: A1.15, Level Shifter.9
unnamed: A1.16, Level Shifter.10
unnamed: A1.20, J3.23
unnamed: A1.21, J3.25
unnamed: A1.22, J3.27
unnamed: A1.23, J3.29
unnamed: A1.24, J3.31
unnamed: A1.25, J3.33
unnamed: A1.26, J3.35
unnamed: Diode.2, J1.4, J1.2.4
unnamed: Down.1, R1.2
unnamed: Left.1, R3.2
unnamed: R4.2, Right.1
unnamed: R2.2, Up.1
unnamed: J1.1, J1.2.1, Level Shifter.3
unnamed: J1.2, J1.2.2, Level Shifter.4
unnamed: J1.6, J1.2.6, Level Shifter.2
unnamed: J1.7, J1.2.7, Level Shifter.1
unnamed: J1.8, J1.2.8, Level Shifter.5

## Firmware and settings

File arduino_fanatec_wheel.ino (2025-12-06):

#include "pins_arduino.h" 
#include <avr/pgmspace.h>

#define HAS_TM1637_DISPLAY	// comment out if you're not using a TM1637 4 digits 7 segment display
#ifdef  HAS_TM1637_DISPLAY
#include <TM1637Display.h>
#define TM_CLKPIN 3
#define TM_DIOPIN 4
#define TM_BRIGHTNESS 5		// (0..7), sets the brightness of the display. 0=min, 7=max
TM1637Display display = TM1637Display(TM_CLKPIN, TM_DIOPIN);
uint8_t TM_data[] = { 0x00, 0x00, 0x00, 0x00 };
const uint8_t TM_race[] = { 0x50, 0x77, 0x58, 0x79 };
const uint8_t TM_crc[] = {0x39, 0x50, 0x39};
#endif

#define DISPLAY_CRC8_MATCH_ON_SERIAL             // keep this and the next line uncommented, until you get many more "crc8 match" lines on the serial port, than crc8 mismatch lines. (I am mostly getting somewhere between 10 to 200 "match" lines before a single "mismatch" line)
#define DISPLAY_CRC8_MISMATCH_ON_SERIAL          // once you know the SPI port is mostly receiving data correctly, you can comment out both lines (or use them for easy debugging)
                                                   // Note: while serial messages are being sent, buttons are sometimes released (by the wheelbase firmware). Which in turns means that if you're holding a button, it will flicker randomly instead of staying held if serial messages are being generated. (Even if serial communication is disconnected). So make sure that once everything works properly, you comment these options out.
//#define DISPLAY_CRC8_MISMATCH_ON_ALPHANUMERIC    // use this if you'd like to get a 'CrC' message displayed on the alphanumeric display, each time there's a crc8 mismatch, which means bad SPI communication with the wheelbase. My advice: always keep this commented. If you do have some SPI communication issues, this might help you to know when communication is faulty without looking at the serial monitor.
//#define DISPLAY_ALPHANUMERIC_DATA_WHEN_MISMATCH_ON_SERIAL  // When getting some (likely broken) alphanumeric text on a packet with mismatched crc8, you might want to view the text on the serial monitor. In that case uncomment this line. (keep this commented to tidy things up)

#define HAS_ANALOG_DPAD
//#define DEBUG_ANALOG_DPAD	// print the DPAD value on the alphanumeric display. Only relevant if you have an analog dpad, and only when trying to get the DPAD working. once it's working - uncomment this. (Dpad value is always sent to serial monitor)
#ifdef  HAS_ANALOG_DPAD
#define DPADPIN A0
int prevDpadVal = 0;
#endif

#define dataLength 33
#define CS_ISR 2		// connect SPI Cable Select pin to Arduino's D2 & D10. (See schematics)
#define PRINTBIN(Num) for (uint32_t t = (1UL << (sizeof(Num) * 8) - 1); t; t >>= 1) Serial.write(Num& t ? '1' : '0'); // Prints a binary number with leading zeros (Automatic Handling)

#define HASBUTTONS	// use digital and analog pins for steering wheel buttons. Note: Pins A7 and A6 do not have an internal pullup resistor. Serial data pins: D0, D1. SPI pins: D2, D10, D11, D12, D13. Display Pins: D3, D4. The rest of digital and analog pins can be used for buttons. (also AFAIK A6 and A7 can only be used for analogRead()  )
#ifdef HASBUTTONS
#define buttonsnum 6									// how many buttons are you using?
uint8_t buttonsPins[] = { A5, A4, A3, A2, 8,  9};		// what arduino pins are you using? 
uint8_t buttonsBits[] = { 8,  5,  13, 11, 9, 12};		// what bits do you want each button to affect? use the last comment in this file as reference.
#endif

uint8_t mosiBuf[dataLength];	// buffer for the incoming data on the mosi line.	
volatile unsigned long lastPrintMillis = 0;
int selectedButtonByte = 2;		// button bytes are 3rd to 5th. initialize to 1st relevant byte.
uint8_t incByte, prevPrintedByte, prevAlphaDisp[3];
volatile uint8_t isrIndex = 0;
unsigned long delayMillis = 400; // wait at least the delay time since last spi communication before printing out whatever came in.

// CRC lookup table with polynomial of 0x131
PROGMEM const unsigned char _crc8_table[256] = {
  0, 94, 188, 226, 97, 63, 221, 131,
  194, 156, 126, 32, 163, 253, 31, 65,
  157, 195, 33, 127, 252, 162, 64, 30,
  95, 1, 227, 189, 62, 96, 130, 220,
  35, 125, 159, 193, 66, 28, 254, 160,
  225, 191, 93, 3, 128, 222, 60, 98,
  190, 224, 2, 92, 223, 129, 99, 61,
  124, 34, 192, 158, 29, 67, 161, 255,
  70, 24, 250, 164, 39, 121, 155, 197,
  132, 218, 56, 102, 229, 187, 89, 7,
  219, 133, 103, 57, 186, 228, 6, 88,
  25, 71, 165, 251, 120, 38, 196, 154,
  101, 59, 217, 135, 4, 90, 184, 230,
  167, 249, 27, 69, 198, 152, 122, 36,
  248, 166, 68, 26, 153, 199, 37, 123,
  58, 100, 134, 216, 91, 5, 231, 185,
  140, 210, 48, 110, 237, 179, 81, 15,
  78, 16, 242, 172, 47, 113, 147, 205,
  17, 79, 173, 243, 112, 46, 204, 146,
  211, 141, 111, 49, 178, 236, 14, 80,
  175, 241, 19, 77, 206, 144, 114, 44,
  109, 51, 209, 143, 12, 82, 176, 238,
  50, 108, 142, 208, 83, 13, 239, 177,
  240, 174, 76, 18, 145, 207, 45, 115,
  202, 148, 118, 40, 171, 245, 23, 73,
  8, 86, 180, 234, 105, 55, 213, 139,
  87, 9, 235, 181, 54, 104, 138, 212,
  149, 203, 41, 119, 244, 170, 72, 22,
  233, 183, 85, 11, 136, 214, 52, 106,
  43, 117, 151, 201, 74, 20, 246, 168,
  116, 42, 200, 150, 21, 75, 169, 247,
  182, 232, 10, 84, 215, 137, 107, 53
};

// Uni hub packet (change to other steering wheels in setup() )
uint8_t returnData[dataLength] = { 0xA5, 0x03, 0x00, 0x00, 0x00, 0x00, 0x00, 0x00, 0x00, 0x00, 0x00,
				  0x00, 0x00, 0x00, 0x00, 0x00, 0x00, 0x00, 0x00, 0x00, 0x00, 0x00,
				  0x00, 0x00, 0x00, 0x00, 0x00, 0x00, 0x00, 0x00, 0x00, 0x00, 0xfc };

// return CRC8 from buf
uint8_t crc8(const uint8_t* buf, uint8_t length) {
	uint8_t crc = 0xff;
	while (length) {
		crc = pgm_read_byte_near(_crc8_table + (*buf ^ crc));
		buf++;
		length--;
	}
	return crc;
}


void setup()
{
	pinMode(MISO, OUTPUT);		// usually when using SPI, arduino will automatically define MISO as output, but not when doing SPI slave.
	pinMode(SCK, INPUT);
	pinMode(MOSI, INPUT);
	pinMode(CS_ISR, INPUT);		// connecting CS_ISR pin (D2) to the SS pin (D10) is crucial. See the schematics.
	pinMode(SS, INPUT);			

#ifdef HASBUTTONS
	for (int i = 0; i < buttonsnum; i++) {
		pinMode(buttonsPins[i], INPUT_PULLUP);
	}
#endif

	returnData[1] = {0x03}; // for ClubSport Porshe 918 RSR - This is the only option that I'm implementing right now.
				//    {0x01} for BMW M3 GT2, {0x02} for ClubSport FORMULA, (0x04) for Uni hub
	Serial.begin(250000);

#ifdef HAS_ANALOG_DPAD
  pinMode(DPADPIN, INPUT);
#endif

#ifdef HAS_TM1637_DISPLAY
	display.clear();
	display.setBrightness(TM_BRIGHTNESS);
	display.setSegments(TM_race);
	delay(1000);
	display.clear();
#endif

	attachInterrupt(digitalPinToInterrupt(CS_ISR), cableselect, RISING);
	// SPCR BYTE should be: 11000100   note to self: by raw_capture.ino and fanatec.cpp spi settings, of btClubSportWheel by Darknao, SPI settings are SPI_Mode0 & MSBFIRST. but with logic scope I see that CPHA 1 (falling!) is used by wheel base, which means SPI_MODE1. (and MSBFIRST)
	// (Mode 1 - clock is normally low (CPOL = 0), and the data is sampled on the transition from high to low (trailing edge) (CPHA = 1))
	SPCR |= _BV(SPE);		// turn on SPI
	SPCR |= _BV(SPIE);		// turn on interrupts
	SPCR |= _BV(CPHA);		//turns on CPHA. as I found the CSW wheelbase to use it, with logic scope.
	Serial.print("SPCR byte (binary):");
	Serial.println(SPCR, BIN);   //prints byte as binary
}

void cableselect() {					// When CS line goes high - the rim should get ready to transmit the next returnData buffer, right from the begining. (so that the first byte (0xA5) will be sent out on the first Clock cycle (and after CS line went Low)
	SPCR &= ~_BV(SPIE);					// turn OFF interrupts
	SPDR = returnData[0];				// load first byte into SPDR single-byte's buffer
	isrIndex = 0;						// on next SPI interrupt(SPI_STC_vect), load the 2nd byte
	SPCR |= _BV(SPIE);					// turn on interrupts
}

// SPI interrupt routine
ISR(SPI_STC_vect)				// Note: this routine takes 6 us, and happens once 8 bits are recieved through SPI.
{	
	byte c = SPDR;
	mosiBuf[isrIndex] = c;
	isrIndex++;
	if (isrIndex >= dataLength) {
		isrIndex = 0;
	}
	SPDR = returnData[isrIndex];
}

void loop() {
	readSerial();
	readButtons();
	calcOutgoingCrc();
	printButtonByteToSerial();
	bool crc8Stat = checkIncomingCrc();
	refreshAlphanumericDisplays(crc8Stat);
}

void readButtons() {
#ifdef HASBUTTONS
		for (int i = 0; i < buttonsnum; i++) {
			if (!digitalRead(buttonsPins[i])) {				// if this input is low the button is pressed. Reverse logic: all button inputs use the internal input pullup, and pressing the button completes the path to ground)
				buttonBitChange(buttonsBits[i], true);		// raise the correct button bit, as defined in buttonsBits[]
			}
			else {
				buttonBitChange(buttonsBits[i], false); 	// drop bit
			}
		}
#endif

#ifdef HAS_ANALOG_DPAD
/*
	VALUE		MIDPOINT	BUTTON							DpadVal
		1023	933.5		nothing							0
		844		763			right							1	
		682		639.5		left							2
		597		505.5		left+right (calibrate center)	3
		414		299			down							4
		184		164.5		up								5
		145		72.5		up+down (menu)					6
		0		0			Dpad button						7
*/
//In case you've used different resistors to what I used, uncomment the serial print command here to find your analog read values: 
//Serial.println(analogRead(DPADPIN));
	int DpadRead = analogRead(DPADPIN);
	int DpadVal = 0;
	if (DpadRead > 933) DpadVal = 0; else
		if (DpadRead > 763) DpadVal = 1; else
			if (DpadRead > 639) DpadVal = 2; else
				if (DpadRead > 505) DpadVal = 3; else
					if (DpadRead > 299) DpadVal = 4; else
						if (DpadRead > 164) DpadVal = 5; else
							if (DpadRead > 72) DpadVal = 6; else
								DpadVal = 7;

	if (DpadVal != prevDpadVal) {		// only if button has changed, do something
		Serial.print("Dpad button:");
		Serial.println(DpadVal);
#if defined HAS_ANALOG_DPAD && defined HAS_TM1637_DISPLAY && defined DEBUG_ANALOG_DPAD
		display.showNumberDec(DpadVal, false,1,3);		// print the dpad value on the lcd screen
#endif	
		dPadBitChange(prevDpadVal, false);	// turn the previous Dpad button bit off.
		dPadBitChange(DpadVal, true);		// turn the current Dpad button bit on.		
	}
	prevDpadVal = DpadVal;
#endif

}

void dPadBitChange(uint8_t dPadVal, bool bitOn) {
	// sets (raises or lowers) the correct button bits according to the Dpad button that was pressed or released
	switch (dPadVal) {
	case 0: break;
	case 1:	// right
		buttonBitChange(3, bitOn); break;
	case 2:	// left
		buttonBitChange(2, bitOn); break;
	case 3: // left+right (calibrate wheel center point)
		buttonBitChange(18, bitOn);			// Dpad button
		buttonBitChange(19, bitOn); break;	// Joystick button
	case 4:	// down
		buttonBitChange(4, bitOn); break;
	case 5:	// up
		buttonBitChange(1, bitOn); break;
	case 6: // up+down (menu)
		buttonBitChange(22, bitOn); break;
	case 7: // Dpad button
		buttonBitChange(18, bitOn); break;
	}
}

void buttonBitChange(uint8_t buttonBit, bool bitOn) {
	// changes a selected bit in one of the 3 button bytes to either on (1) or off (0). Valid values for buttonBit is 1 to 24. See buttons list in last comment.
	if (bitOn) {
		returnData[2 + ((buttonBit - 1) / 8)] |= (1 << (((buttonBit - 1) % 8)));
	}
	else {
		returnData[2 + ((buttonBit - 1) / 8)] &= ~(1 << (((buttonBit - 1) % 8)));
	}
}

void readSerial()
  // reads user inputs from serial connection. i = print mosI data, o = print misO data, d = view what is displayed on the rim's alphanumeric display. letters (A,B,C) = selects corresponding button byte (first second or third), numbers (1..7) = changes bits inside the selected byte. So user can send button presses to the wheelbase without having any physical buttons attached.
{
	if (Serial.available() > 0) {
		incByte = Serial.read();
		Serial.println((char)incByte);
		if (incByte == 'i')
			printmosibuf();
		if (incByte == 'o')
			printmisobuf();
		if (incByte == 'd')
			refreshAlphanumericDisplays(true);
		if ((incByte >= 'A') && (incByte <= 'J')) {		// send A,B,C to choose 1st, 2nd, 3rd button byte
			selectedButtonByte = (incByte - 'A' + 2); 	// first button byte is 3rd in array, or cell no 2 to cell no 4 in array
			Serial.print("Selected button byte:");
			Serial.println(selectedButtonByte);
			PRINTBIN(returnData[selectedButtonByte]);
			Serial.print("			");
			printHex(returnData[selectedButtonByte], 2);
			Serial.println();
		}
		if ((incByte >= '1') && (incByte <= '8'))
		{
			returnData[selectedButtonByte] ^= (1 << (incByte - '1'));	// toggles bit correcsponding to number read by serial print
			printmisobuf();
		}
	}
}

void printHex(int num, int precision) {
	char tmp[16];
	char format[128];
	sprintf(format, "0x%%.%dX", precision);
	sprintf(tmp, format, num);
	Serial.print(tmp);
}

void refreshAlphanumericDisplays(bool crc8Stat) {
	// display current alphanumeric information through serial port / TM1637 display
	bool displaychanged = false;
	for (int i = 2; i <= 4; i++) {						// cells 2 to 4 in miso data is alphanumeric data
		if (mosiBuf[i] != prevAlphaDisp[i - 2]) {		// if anything on the display changed, reprint
			displaychanged = true;
			break;
		}
	}
#ifdef    DISPLAY_ALPHANUMERIC_DATA_WHEN_MISMATCH_ON_SERIAL   // print to serial in any case (even if packet has bad crc8). (only print to alphanumeric display if it has good crc8)
  if (displaychanged) {                     
#else                                                         // prints to serial monitor and alphanumeric display only if packet has good crc8
  if (crc8Stat && displaychanged) {                     
#endif


		for (int i = 2; i <= 4; i++) {
			uint8_t p = mosiBuf[i] & 0x7F;				// remove the . (dot) bit
			switch (p) {
			case 0x3f:	Serial.print("0"); break;
			case 0x6:	  Serial.print("1"); break;
			case 0x5b:	Serial.print("2"); break;
			case 0x4f:	Serial.print("3"); break;
			case 0x66:	Serial.print("4"); break;
			case 0x6d:	Serial.print("S"); break;
			case 0x7d:	Serial.print("6"); break;
			case 0x7:	  Serial.print("7"); break;
			case 0x7f:	Serial.print("8"); break;
			case 0x6f:	Serial.print("9"); break;
			case 0x39:	Serial.print("C"); break;
			case 0x38:	Serial.print("L"); break;
			case 0x8:	  Serial.print("_"); break;
			case 0x79:	Serial.print("E"); break;
			case 0x54:	Serial.print("n"); break;
			case 0x71:	Serial.print("F"); break;
			case 0x76:	Serial.print("H"); break;
			case 0x5c:	Serial.print("o"); break;
			case 0x77:	Serial.print("A"); break;
			case 0x7c:	Serial.print("b"); break;
			case 0x5e:	Serial.print("d"); break;
			case 0x50:	Serial.print("r"); break;
			case 0x30:	Serial.print("I"); break;
			case 0x73:	Serial.print("P"); break;
			case 0x78:	Serial.print("t"); break;
			case 0x40:	Serial.print("-"); break;
			case 0x3e:  Serial.print("u"); break;
			case 0x2A:	Serial.print("*"); break;   // this should really be a floating 'o' (displayed on the top square) but I couldn't find an ascii character for that
			default:	printHex(p, 2);	   break;
			}
			if (mosiBuf[i] & 0x80)							// select only the . (dot) bit
				Serial.print(". ");
			else
				Serial.print("  ");

      if (crc8Stat)
			  prevAlphaDisp[i - 2] = mosiBuf[i];    // only update the previous display array if current packet has good crc8. (If not doing this test, text will not print out to alphanumeric display properly)
		}
    if (!crc8Stat)
      Serial.println(" [crc8 mismatch]");
    else
		  Serial.println();
#ifdef HAS_TM1637_DISPLAY
    if (crc8Stat) {                            // Only refresh the alphanumeric display if the current packet is intact (has proper crc8 attached to it) {
  		for (int i = 2; i <= 4; i++) {
  			TM_data[i-2] = mosiBuf[i];
  		}
  		display.setSegments(TM_data);
    }
#endif
	}
}

void printButtonByteToSerial() {
// Prints the selected button byte to Serial, if it was changed. The button byte can be selected by sending either A,B or C through the serial monitor. The bits in the selected button byte can either be changed by the serial monitor (sending 1 to 7 raises / lowers a specific bit,) or by pressing one of the physical buttons, if you have any attached.
	if (millis() > lastPrintMillis + delayMillis) {
		if (prevPrintedByte != returnData[selectedButtonByte]) {
			PRINTBIN(returnData[selectedButtonByte]);
			Serial.print("			");
			printHex(returnData[selectedButtonByte], 2);
			Serial.println();
		}
		prevPrintedByte = returnData[selectedButtonByte];
		lastPrintMillis = millis();
	}
}

void printmosibuf() {
	Serial.print("MOSI:");
	for (int i = 0; i < dataLength; i++)
	{
		printHex(mosiBuf[i], 2);
		//Serial.print(mosiBuf[i],HEX);
		Serial.print(" ");

	}
	Serial.println();
}

void printmisobuf() {
	Serial.print("MISO:");
	for (int i = 0; i < dataLength; i++) {
		printHex(returnData[i], 2);
		//Serial.print(returnData[i], HEX);
		Serial.print(" ");
	}
	Serial.println();
}

void calcOutgoingCrc() {
	returnData[dataLength - 1] = crc8(returnData, dataLength - 1);		// calculates crc8 for outgoing packet
}

bool checkIncomingCrc() {		// crc check for incoming data. returns true if correct crc8 is found in the incoming data
	uint8_t crc = crc8(mosiBuf, dataLength - 1);		//Serial.print("calc crc");			//Serial.println(crc,HEX);
	if (crc != mosiBuf[dataLength - 1]) {
#ifdef DISPLAY_CRC8_MISMATCH_ON_SERIAL
		Serial.println("_____________incoming data crc8 mismatch!________");
		printmosibuf();
#endif
#ifdef DISPLAY_CRC8_MISMATCH_ON_ALPHANUMERIC
		display.setSegments(TM_crc);
#endif
  return false;
	}
  else
#ifdef DISPLAY_CRC8_MATCH_ON_SERIAL
  Serial.println("crc8 match!");
#endif
  return true;
}


/*
Clubsport wheel buttons, by bit, from 3rd byte on miso array to 5th byte.
The buttons numbers appear in the fanatec driver (mouse settings tab), and also in the 'clubsport Porsche 911 buttons.png' file.

A
1	D-pad Up
2	D-pad Left
3	D-pad Right
4	D-pad Down
5   Button 11
6   Button 3
7   Button 6
8   Button 4

B
9(1)    Right Paddle
10(2)	Button 2			(top left, right one)
11(3)   Button 8			(bottom left, lower)
12(4)   Left paddle
13(5)   Button 1			(top left, left one)
14(6)   Button 5			(bottom left, higher)
15(7)   Button 9			(3 buttons in triangle, left)
16(8)   Button 10			(3 buttons in triangle, right)

C
17(1)	Button 21 in contentmanager. Does not show up in fanatec's driver
18(2)	D-pad Button
19(3)	Joystick Button
20(4)	Button 7			(3 buttons in triangle, top)
21(5)	Button 27 in contentmanager. Does not show up in fanatec's driver
22(6)	Menu button. Button 28 in contentmanager. Does not show up in fanatec's driver)
23(7)
24(8)

example: button 8 on fanatec's driver, number 11 on this list, is controlled by 3rd bit on the 2nd byte, of the 3 bytes that control buttons.

C6 - enters menu
B8C6 - enters shifter calibration mode

To calibrate wheel center, 
A. Using the serial monitor, send:
C6 6 23 23 6 6. (each space here means: hit return)

B. Using the Dpad:
Enter the menu by pressing both up+down bubttons on the Dpad,
S_1 will appear on the serial monitor and on the alphanumeric display,
Press both left+right buttons on the Dpad to calibrate wheel center,
Press both up+down on the Dpad to exit menu.

*/

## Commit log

2019-07-03 fix alphanumeric display bug regarding characters that did not change
    [arduino_fanatec_wheel.ino]
2019-09-15 readme - arduino nano tested
2019-10-05 Simple schematics to show the connection between Fanatec's round wheelbase plug, a logic shifter, and an Arduino nano. Credit to Jonbakhol
2019-12-31 new schematics and pcb layout. To be manufactured from a single layer board (bottom only). Top can easily be connected with some pieces of wire. (in the 3d screenshot file, the bottom layer is displa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
    [arduino-fanatec-pcb.kicad_pcb, arduino-fanatec-pcb.sch, noname.kicad_pcb]
2019-12-31 Added schematics and PCB (work in progress) with 7 segments display and Dpad+menu buttons. Thinking about connecting all these buttons to one analog input, but reading analog inputs takes longer. OTO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
    [arduino-fanatec-pcb.kicad_pcb, arduino-fanatec-pcb.sch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]
2020-04-10 The PCB now supports the 4 digits alphanumeric display and 5 buttons D-pad, which are read by a single analog pin on the arduino. see README.md in schematics & pcb layout for more information about t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
    [Fanatec_PodiumWB-DD1-DD2.SLDPRT, arduino fanatec wheel.SLDASM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]
2020-04-13 debugging the cable select pin
2020-04-13 button debugging, for digital / analog buttons that are each connected to a single input on the arduino (with internal input pullup, and ground connection)
2020-04-27 print dpad value on alphanumeric display - nicer & simpler
2020-04-27 buttons and Dpad code now uses sensible functions
2020-04-28 updated PCB layout and schematics, including Dpad, Alphanumeric display, buttons, Diode - and many bug fixes
    [arduino-fanatec-pcb-simplified.sch, arduino-fanatec-pcb.kicad_pcb]
2022-03-13 see https://github.com/lshachar/Arduino_Fanatec_Wheel/issues/20
2022-12-19 Updated the PCB front silkscreen, exported Geber files for manufacturing according to jlcpcb's requirements
    [arduino-fanatec-pcb-B_Cu.gbl, arduino-fanatec-pcb-B_Cu.gbr, arduino-fanatec-pcb-B_Mask.gbs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]
2023-01-04 new: "CRC8 Match" messages will be generated on the serial connection, for easier debugging of the SPI interface, which is the issue most users experience. I am getting somewhere between 10 to 200 "m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
    [arduino_fanatec_wheel.ino]
2023-01-04 bug solved (with debug code)
    [arduino_fanatec_wheel.ino]
2025-12-06 Fixing alphanumeric display jittering: when packet was received with a bad crc8, do not display the text on the alphanumeric display. For the serial monitor, you can uncomment the line: #define DISPL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
    [arduino_fanatec_wheel.ino]
